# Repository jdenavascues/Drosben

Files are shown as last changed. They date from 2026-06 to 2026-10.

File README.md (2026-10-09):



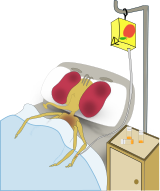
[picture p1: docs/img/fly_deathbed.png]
deathbed


# Drosben: a method for scaling up lifespan analysis of _Drosophila_

_Drosophila melanogaster_ is a powerful model organism to study ageing, or any other processes where lifespan is a useful life history trait, because the fly lends itself to large demographic studies to measure survival time and mortality rates. However, performing these experiments is time-consuming, as they require many manual passages of fly vials to keep them on fresh food and record events. 

We have developed a toolkit that allows transferring flies from 12 tubes into fresh ones ('flipping') simultaneosly, which we have named _Drosben_ (a portmanteau of _Drosophila_ and _trosben_, Welsh for sommersault). Drosben comprises both hardware (which can be made cheaply with 3D printing and minimal DIY modifications) and software (a simple python module with notebooks for usage). One speeds the manual labour, and the other one speeds the data recording -- producing a quick preliminary analysis and a spreadsheet ready to be analysed in a more targeted way in R with the package `survival`.

---

For more details, please refer to our paper describing the Drosben system together with a few new observations using this approach:

Terrence M. Trinca, Pau Berenguer-Molins, Cristina Fernández-García, Joaquín de Navascués.

Drosben, an affordable system for scalable survival analysis in _Drosophila_.

bioRxiv 2026.07.02.736118; doi: [https://doi.org/10.64898/2026.07.02.736118](https://www.biorxiv.org/content/10.64898/2026.07.02.736118)

---

# Overview

The Drosben system comprises:

- **3D-printed hardware** that has to be printed and assembled (glueing and some cutting).
- **Software** that has to be installed manually and used in three steps:

- _'Colour calibration'_ to validate a set of 3 marker pens for automatic recognition (done only once or if a new pen set needs to be tested);
- _'Experiment initialization'_ to record experimental design details and produce experiment-specific data recording sheets (done once per experiment);
- _'Data compilation/analysis'_ to capture the data from scanned datasheets (done once at the end of an experiment, but can also be done along the way to monitor progress).

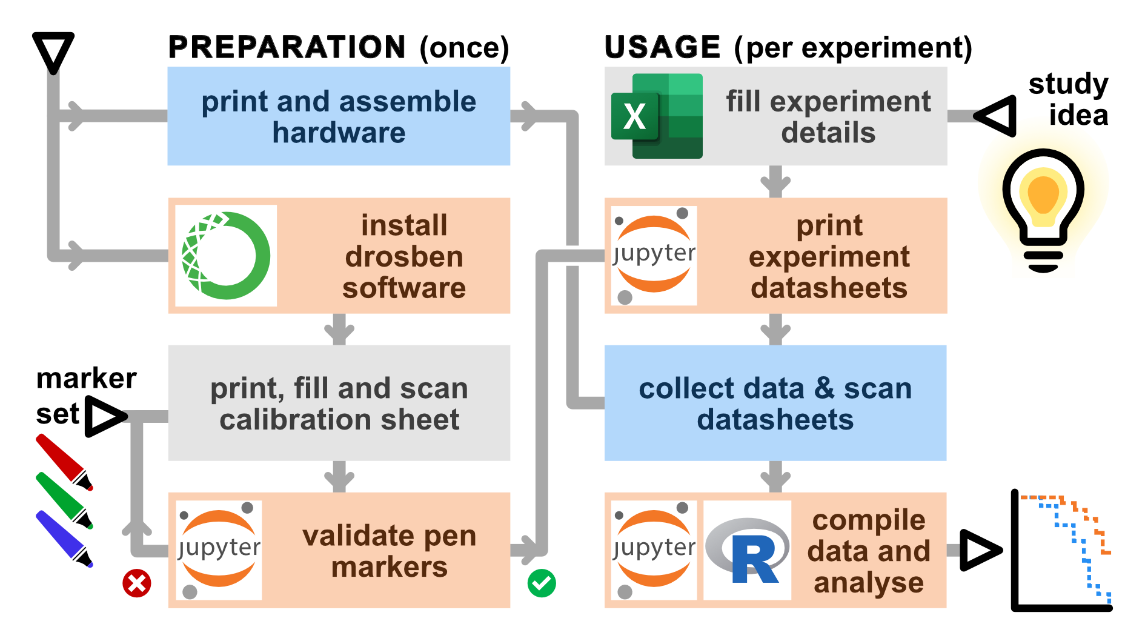
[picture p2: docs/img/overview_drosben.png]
Overview of the Drosben system: preparation and usage


---

# 1. The Drosben hardware

The hardware components are designed to improve handling speed of vials during fly transfer to fresh food.

## 1.A. Components

The Drosben hardware components are:
- The rack and lid that houses 12 _Drosophila_ vials,
- The depositor for distributing the flies initially into the vials,
- The multiflipper and its slider, for transferring the flies from a rack into another one with fresh vials.

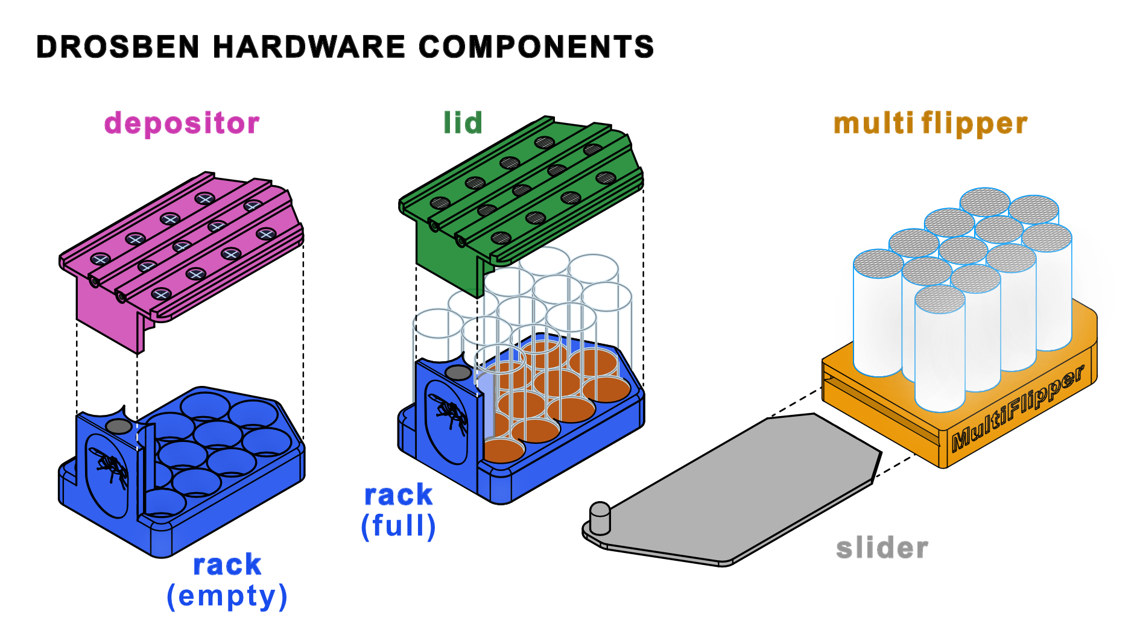
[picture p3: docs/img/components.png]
components of Drosben hardware


## 1.B. Required equipment and materials  

See the [hardware README](hardware/README.md) for the model files for 3D printing and some details on their assembly/preparation for usage.

+ **A 3D printer** capable of printing 1.75 mm PLA or ABS filament. We have printed the necessary parts successfully in a [Prusa i3 MK3S+](https://www.prusa3d.com/product/original-prusa-i3-mk3s-10th-anniversary-edition-3d-printer/) and a [Bambulab A1 mini](https://bambulab.com/en/a1-mini). Alternatively, you can send the files to a printer shop.

+ **Slicing software** for your 3D printer. We have used Cura Ultimaker and Bambulab Studio.

+ **Clear acrylic tube** with 25 mm outer diameter and 2 mm thickness (23 mm ID). These can be bought cut to measure from local or online retailers, or bought by the metre and take to a workshop for cutting. A cheaper alternative is to buy a long piece and cut it down yourself (see the [hardware README](hardware/README.md)).

+ **Stainless steel or plastic thin mesh**; those described for insect netting would work and are relatively cheap. A piece of ~15 x 20 cm will be enough for a single Multiflipper.

+ **Cyanoacrylate-based universal glue** such as those manufactured by Gorilla, Everbuild or Superglue. There is no need to use a special manufacturer but we prefer the gel presentation (as opposed to 'thin', 'extra thin' or 'highly penetrant') as these will run everywhere and can create frosting in the acrylic tubes.

+ **Silicon rubber sheet** of 1mm thickness, cut from a piece of approximately 30 x 20 cm (half to make a single Depositor, the other half to protect the Slider while gluing the Multiflipper).

+ **N45 Neodymium magnets** (3mm thick, of diameters 12mm and 6mm). Four will be needed for one Multiflipper (6mm &#x2300;), two for one Rack and Lid, and one for a Depositor (12mm &#x2300;).

> [!TIP]
> The fumes from the cyanoacrylate may leave a frost mark on the acrylic tubes; to prevent this, one may use use instead acrylic-specific glue to bind the tube segments to each other.

> [!CAUTION]
> **[1]** 3D printers release plastic microparticles and therefore pose a chemical hazard: make sure you follow local health and safety rules (and common sense) if you print yourself. **[2]** Cutting acrylic tubing yourself poses safety hazards (cuts and grazes): make sure you follow local health and safety rules (and common sense) if doing so. This also applies (somewhat less so, but to some extent) to rubber sheet. **[3]** Both cyanoacrylate and acrylic glues pose chemical hazards: make sure you follow local health and safety rules (and common sense) when using them.

## 1.C. Hardware usage

The Drosben hardware is used in three steps.

First, print and cut the rack labels for your experiment and place each in the slot of a rack, so you can see experimental conditions. Place the corresponding flies in each of the tubes using a pooter, with the distributor covering the tubes. The rubber valves of the distributor (see the [hardware README](hardware/README.md)) prevent flies from escaping. Quickly swap the distributor by a lid, where instead of valves, slits allow breathing. Both snap in place thanks to the rare-earth magnets and two rigid push-click spots. This starts the experiment. If you want to record the data blind to the experimental conditions, flip now each rack label so it is the QR side that shows.

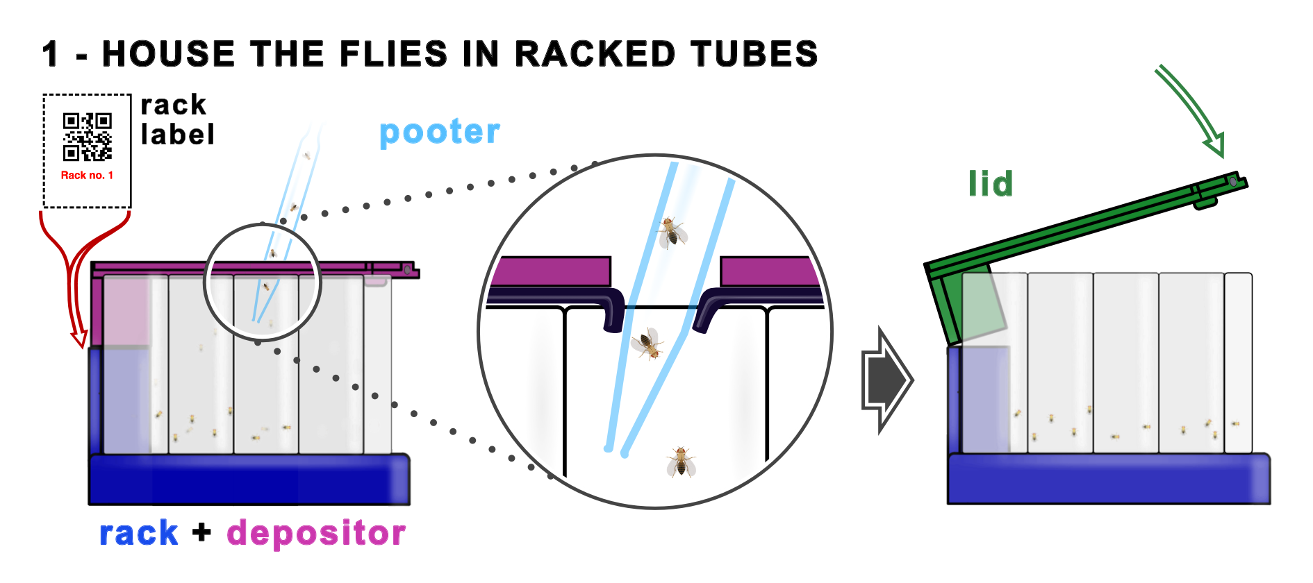
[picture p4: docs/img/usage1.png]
step1


Next, and every time flies need passaging into vials with fresh food, swap the lid by the multiflipper, flip the assemble and gently tap the flies into the multiflipper chambres; cover them with the slider, which will be held in place by magnets (see the [hardware README](hardware/README.md)). Set the rack with old tubes aside for recording deaths and place a new one on top of the multiflipper. Remove the slider, flipe the assemble and tap the flies into the new tubes. Swap the multiflipper and the lid and place the tubes in the incubator.

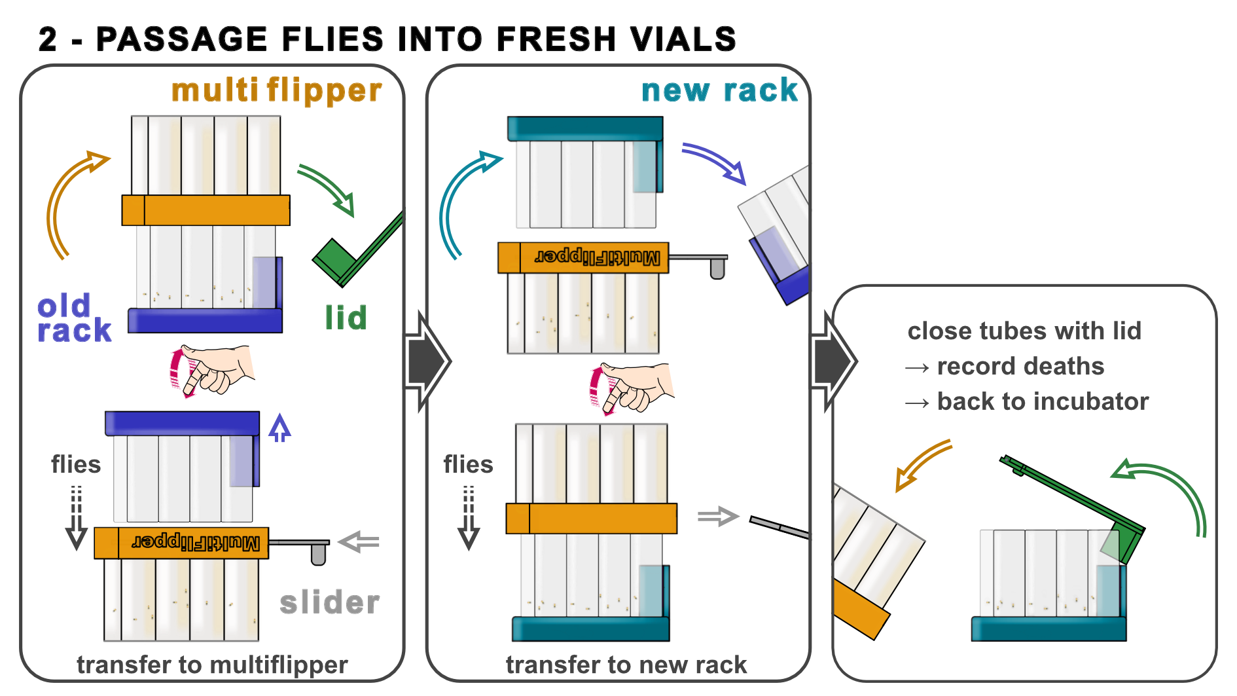
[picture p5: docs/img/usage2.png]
step2


Finally, every time you passage the flies, identify the datasheet corresponding to the rack you are passaging. Explicit datasheets will have the rack no. and the experiment 'name' and conditions in the header. For blind recording, read the QR code with the phone and match the reading with the last 5 characters of the experiment ID. Then, on the next available grid on the datasheet, record:
- days since last flip,
- deaths (matching the dead flies stuck to the bottom of the tubes),
- censorings (escaped flies or flies stuck alive to the bottom of the tubes), and
- carried-overs (dead flies that fall into the fresh vials).
When the experiment is finished (or you want to inspect the data), scan the datasheets and use the software.

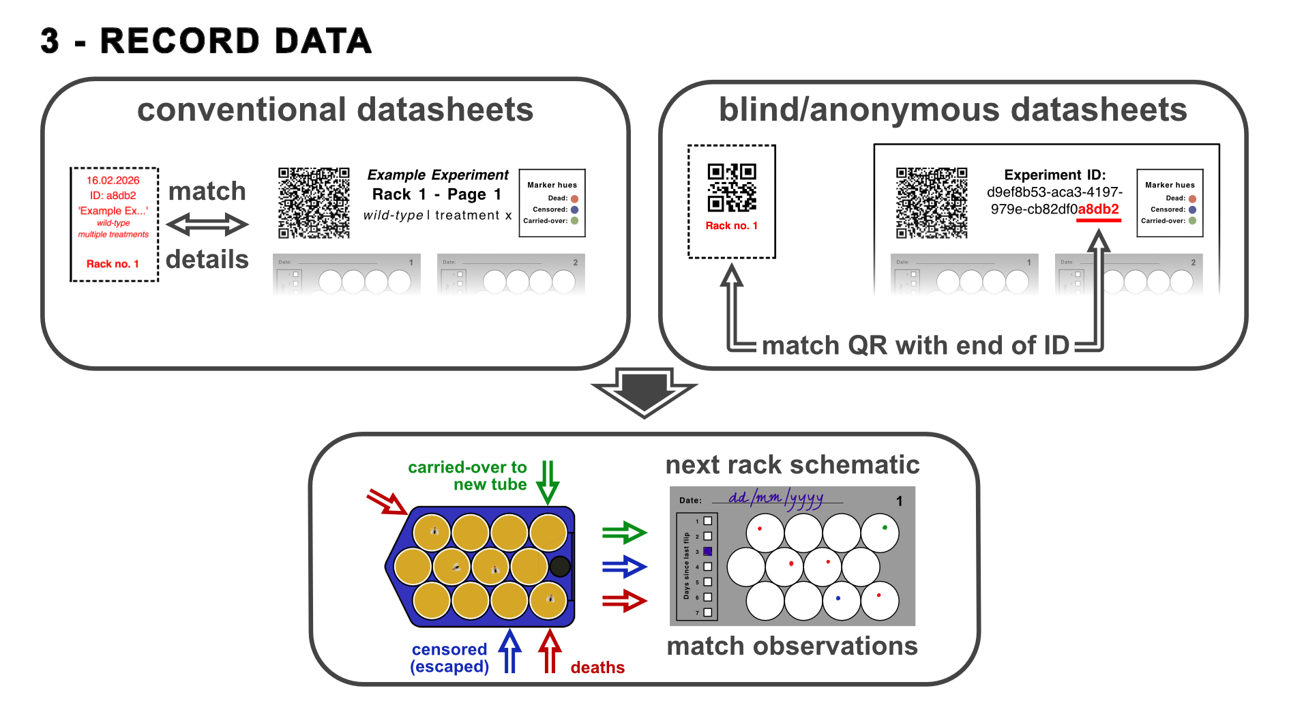
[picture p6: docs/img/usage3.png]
step3


---

# 2. The Drosben software

We wrote a python package to speed up the data collection, both when recording fly deaths and when compiling the observations in electronic form. It takes advantage of the shape of the tubes as held in the rack, so the user at the bench can quickly record deaths as pen marks on a printed template; then these can easily be scanned, automatically detected with computer vision, and compiled into a spreadsheet for analysis. So, while the hardware can be used without the software, this is not the case the other way around; however, the drosben system is more effective when both hardware and software are used together.

Apart from the hardware components, you will also need:

+ A colour printer
+ A device to scan A4 documents (ideally, a flatbed scanner, but a phone can work too)
+ 3 colour markers. We normally use Sharpie fine point markers in red, green and blue. More colourblind-friendly combinations could be obtained using yellow, orange, blueish red, purple light and blue.

> [!IMPORTANT]
> **Why using 3 colours?** Most of the data is collected with one colour (dead flies). However, sometimes flies can escape; while they can be ignored, the best practice is to record these as censored events -- hence the second colour. The third colour comes from the fact that, occasionally, a dead fly does not get stuck to the food; it dries too quickly and is carried over the new tube with the alive flies. These 'events' can be detected easily because the 'carried-over' corpses fall to the bottom of the tubes and remain immobile in unnatural positions. Recording this as a normal death can lead to counting the same dead fly as many times as it is carried over until it gets stuck to the food. So, every carried-over event has its own colour, and by recording them every flip they are detected, the software back-tracks the time of observed death to the first carried-over event.

## 2.A. Installation and start

### Installation with _no previous experience_ in programming

If you have _any_ experience programming in Python, you probably can jump to the [next section](#installation-with-any-programming-experience). If you do not have Python or '(ana)conda' installed in your system (or do not know if you do), this section is meant for you.

We are not experienced programmers, so neither our software nor its installer have polished user interfaces. However, they are simple enough and the steps are very constrained. Just bear in mind that instead of clicking and dragging-and-dropping, you will have to type in some simple commands, which we have tried to minimise and explain step by step.

We have written the drosben software in the Python language, using a few specific Python libraries (specialised extensions of the language). For our software to work, specific versions of both Python and the libraries need to be installed together; this is called an 'environment' (for some beginner explanations, see [here](https://realpython.com/python-virtual-environments-a-primer/), [here](https://www.w3schools.com/python/python_virtualenv.asp) or [here](https://www.anaconda.com/blog/anaconda-python-complete-beginners-guide).

Once you have the environment set up, you can open in it a 'working environment', JupyterLab, from where to open and run the so-called 'ipython notebooks' - a sort of live documents where you can mix formatted text (which we use to give you instructions) and snippets of code (which will work as the buttons and check boxes of a polished user interface). You can find basic explanations of what Jupyter Notebooks are and what they look like [here](https://www.datatoinsight.org/jupyter-notebooks) and [here](https://www.datatoinsight.org/jupyter-notebooks); for a bit more information look [here](https://www.datatoinsight.org/jupyter-notebooks) (shortcuts and hotkeys) or [here](https://www.dataquest.io/blog/jupyter-notebook-tutorial/) (with basic exercises); for a video tutorial, I suggest you look [here](https://www.youtube.com/watch?v=Ou-7G9VQugg). All these will give you more than you need, as we will only ask you to:
- open a notebook within JupyterLab
- 'run cells' (Shift-Enter)
- type in some cells the paths to the scans where you collected the data, guided by the instructions.

All this may sound like a lot, but it will be taken cared of by the 'environment manager' [Anaconda](https://www.anaconda.com/). Anaconda has paid options, but to run drosben, a free licence works perfectly; you just need to register.

#### Installing Anaconda

You first need to decide [which Anaconda version you want](https://www.anaconda.com/docs/getting-started/anaconda/install). Anaconda has two interfaces: a graphical one (the 'Anaconda-Navigator') and a command-line. The full version of Anaconda includes the Navigator and takes a minimum of 5Gb of hard disk space. If this is a concern to you, you can instead install Miniconda, which by default only has the command-line interface (CLI). Linux and MacOS systems have built-in 'command-line terminal' apps from where to use the CLI. Windows systems typically do not, but both Anaconda and Miniconda for Windows come with their own terminal apps: "Anaconda Prompt" (just to operate anaconda) and "Anaconda PowerShell Prompt" (more general-purpose). Alternatively, you can install a separate program to run command-line terminals. [MobaXterm](https://mobaxterm.mobatek.net/) is a general-purpose terminal utility and its free home licence is enough for running drosben. 

So, to install Anaconda, visit their [download page](https://www.anaconda.com/download), choose the system (Win/Mac/Linux) and version ('Ana'/'Mini') and run the installer. All of this is done clicking - no command line needed.

#### Copying the drosben source code

At the top of this GitHub page, click on the $${\color{#3E7E40}{\textsf{<> Code &#x2304;}}}$$ button and select 'Download ZIP'. Unzip the contents and move the folder to where you want it to be.

#### Creating the drosben environment

**With Anaconda-Navigator:** Open the Navigator and follow the instructions from the Anaconda tutorial to [import an environment](https://www.anaconda.com/docs/tools/anaconda-navigator/tutorials/manage-environments#importing-an-environment) using a local `.yml` file. The local file for you is `environment.yml`, directly in the `drosben/` folder you just unzipped.

**With command-line:** Open a terminal in your system.
- Linux: press the Super key and type 'terminal'.
- MacOS: navigate to Applications > Utilities > Terminal
- Windows: press the Windows key, type 'Anaconda Prompt' or your utility of choice
Once in the terminal, just run in your terminal (copy-paste-&#x21B5;):
```{bash}
# navigate to where the drosben repository is
cd ~/where/you/have/drosben # substitute this path for the one in your system
# create the environment (drosbenV - name determined by environment.yml)
conda env create -f environment.yml
# activate it
conda activate drosbenV
# install the drosben package as local source
# (this is installed in the drosbenV environment)
pip install drosben
# ONLY if you installed miniconda, JupyterLab needs to be installed separately:
# (this is installed in the drosbenV environment)
conda install -c conda-forge jupyterlab -y
```
Simple!

---

### Installation _with_ any programming experience

If you have any programming experience with python, you can probably jump over this paragraph. If you have programming experience but not with python: for the software to work reproducibly, we need an environment with a specific version of python (3.11) and the libraries used (some in specific versions, too). The environment manager Anaconda does this and installs JupyterLab (an IDE to run the code through computing notebooks).

- [Install Anaconda](https://www.anaconda.com/download) in whichever version you prefer, if you need to.
- Open a shell terminal and run:
```bash
# clone the repository and go to its top directory
cd ~/where/you/want/the/repo
git clone https://github.com/jdenavascues-trincatalyst/drosben.git
cd drosben
# create the environment
conda env create -f environment.yml
# activate it
conda activate drosbenV
# install the drosben package as local source
pip install drosben # note ~/.../drosben is the working directory
# if using miniconda, add JupyterLab
conda install -c conda-forge jupyterlab -y
```

---

### Running the program once installed

JupyterLab will run the notebooks from where you can use the drosben software. To start JupyterLab:

**With Anaconda-Navigator:** Launch the Navigator, go to the Home tab, and find the drop-down menu that selects the environment. It is at the top and will probably read "_All applications_ on _base (root)_". Change _base (root)_ for _drosbenV_, and click on the JupyterLab launch icon.

**With command-line:** In a shell terminal, run:
```bash
conda activate drosbenV
cd ~/.../drosben # so jupyterlab starts there and notebooks are easy to find
jupyter lab
```

Once JupyterLab is active, navigate interactively to the `drosben/notebooks/` directory and open the Notebook you need. The first time, do it in their numerical order. Any alternative IDE that can run the notebooks should work, too.

---

## 2.B. Usage and data analysis

The easiest way to use the software is to run the Jupyter notebooks in order:
- [Colour test template](src/drosben/resources/colour_cal_printout.pdf): Print, fill and scan this template start Notebook #01 (see notebook for detailed instructions).
- [Notebook #01](/notebooks/01_First_Use_Colour_Calibration.ipynb): Validate the pen markers to ensure the three colours will be discriminated without human supervision. This needs be done only once, unless you change the colours.
- [Excel template](src/drosben/resources/experiment_template.xlsx): Before you start an experiment, fill in the experimental details in an Excel template file.
- [Notebook #02](/notebooks/02_Perform_Experiment.ipynb): Read the experiment metadata from the Excel template and generate
    - experiment-specific data recording sheets. These can be anonymous for blind data collection, if desired, and
    - Labels for each of the racks used for the experiment racks (both anonymous or identified).
    - This only needs be run once per experiment.
- [Notebook #03](/notebooks/03_Read_DataSheets.ipynb): Compile the observations recorded in scanned datasheets and run an automated preliminary analysis of the data. This can be done all at once at the end of the experiment or incrementally, in multiple rounds along the way.
- Then move to an R environment (e.g. RStudio) for [Notebook #04](/notebooks/04_Analyse_Data.Rmd)

Recommendations for scanning datasheets and colour calibration sheets:
- Scan the papers at ≥150 dpi
- Save in TIFF/JPEG/PNG/PDF format
- You can use a phone or a flatbed scanner (but see below)
- For datasheets in particular:
    + They require minimal skew (which can be corrected up to a few degrees) or perspetive distorsion (which is not corrected by drosben and needs to be adjusted beforehand).
    + QR corner MUST be visible.

### Further analysis in R

The output of the python notebooks will be a spreadsheet (XLSX/CSV) that can be analysed in python, but is best analysed using the `survival` package in R. The libraries for survival analysis in python are simply not as well developed as in R. To use R, the easiest way is:

- Download the R installer for your system from [CRAN](https://cran.r-project.org/) and follow its instructions for installation.
- Download the RStudio Desktop installer from [posit](https://posit.co/download/rstudio-desktop/) and follow its instructions for installation.
- A nice introduction from absolute zero to R and RStudio is provided by [the Sydney R-Ladies](https://rladiessydney.org/).
- You will need to install the packages [`survival`](https://cran.r-project.org/web/packages/survival/) by Terry Therneau and [`survminer`](https://cran.r-project.org/web/packages/survminer/index.html).
- We do not cover the use of these here at this point. There are multiple tutorials that show how to use these libraries:
    - [Tutorial by Emily Zabor with some basic theory](https://www.emilyzabor.com/survival-analysis-in-r.html)
    - [Tutorial by Shariq Mohammed](https://shariq-mohammed.github.io/files/cbsa2019/1-intro-to-survival.html)
    - [Tutorial at UCLA with some theory](https://stats.oarc.ucla.edu/wp-content/uploads/2025/02/survival_r_full.html)
    - [Tutorial at Datacamp](https://www.datacamp.com/tutorial/survival-analysis-R)
    - [Tutorial by Ho Thi Nhan](https://bookdown.org/nhanhocumc/biodata-r/survival.html)
    - [Tutorial by Aura Frizzati](https://rpubs.com/auraf285/SurvAnalysisR)
    - There's plenty more around...

## 2.C. Troubleshooting

(Under construction)

### Environment issues

If `conda env create -f environment.yml` fails to solve, try the more prescriptive installs (where the versions are more rigidly specified).

First using the pinned `.yml` file, where package versions are specified:
```bash
# with the repository top folder drosben/ as your working directory:
conda env create -f environment_pinned.yml
# follow up with environment activation, etc
```

If that fails, try cloning a locked environment that we used successfully:
```bash
# with the repository top folder drosben/ as your working directory:
conda-lock install -n drosbenV -f conda-lock.yml
# follow up with environment activation, etc
```

### Test the installation

- To run tests:
```bash
pytest -q
```
If this runs without errors, you should be ready to go.

### Jupyter does not seem to have the right libraries

JupyterLab and the Jupyter notebooks will only be 'aware' of drosben if they were initialised within the `drosbenV` environment. If you try to run the notebooks code cells and you get error messages along the lines of `` maybe you have not started from this environment. Create a new cell in the notebook and run:
```python
import os
print(os.environ['CONDA_DEFAULT_ENV'])
del os
```
This code block should print `drosbenV`. If it doesn't, exit JupyterLab with File > Log Out, go back to Anaconda-Navigator or your Terminal and try again the [instructions above](#running-the-program-once-installed).

---

# 3. Contact

- [**Terrence M Trinca**](https://www.bristol.ac.uk/people/person/Terrence-Trinca-4379516b-71e2-40a1-9e22-a4a3fb2bdda9/)
- [**Joaquín de Navascués**](https://www.essex.ac.uk/people/DENAV35604/Joaquin-De%20Navascues)

---

# 4. Acknowledgments

* Hat tip to all the programmers from whom we took tips and tricks found in StackOverflow and GitHub. Their contributions are linked in comments in the code.
* The sickly fly was drawn by [Cristina Fernández García](https://es.linkedin.com/in/fernandezgarciacristina).
* [Flying fly silhouette in one of the figures](https://www.vexels.com/vectors/preview/170043/fly-insect-silhouettes")

---

# 5. License

The contents of this repository are shared through the MIT licence. 

---

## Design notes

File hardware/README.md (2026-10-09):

# Instructions to assemble the Drosben components

> [!CAUTION]
> 
> Assembling the hardware brings chemical and mechanical hazards.
> We give recommendations but you follow them **at your own risk**.
> 
> **THIS IS NOT A RISK ASSESSMENT**. Some precautions are mentioned, but you **must** do your own risk assessment.

You will need:

## Component costs[^*]

| Component | Quantity | Required[^a] | Cost per usage unit |
| :--- | ---: | :--- | ---: |
| (initial materials) | 1 | Per lab | £71.00 |
| Depositor stencil | 1 | Per lab | £0.14 |
| Multiflipper | 1 | Per user | £38.91 |
| Slider | 1 | Per user | £0.50 |
| Depositor | 1 | Per user | £3.49 |
| Rack | 2 | Per cohort | £2.28 |
| Lid | 1 | Per cohort | £0.90 |

## Materials costs

| Material | Quantity (per pack) | Unit | Price[^b] |
| :--- | ---: | :--- | ---: |
| PLA filament | 1000 | g | £18.00 |
| Acrylic tube | 1 | count | £3.00 |
| Nail shaft | 200 | count | £3.50 |
| N52 magnet 12 x 3 mm | 50 | count | £12.00 |
| N52 magnet 10 x 3 mm | 50 | count | £12.00 |
| Woven wire mesh | 3600 | cm² | £20.00 |
| Super glue gel | 30 | g | £4.00 |
| Acrylic cement | 50 | ml | £9.00 |
| Rubber sheet | 100 | cm² | £3.00 |

## Recipes

| Component | Material | Quantity | Unit | Cost per component |
| :--- | :--- | ---: | :--- | ---: |
| Multiflipper | PLA filament | 40 | g | £0.72 |
|  | Acrylic tube | 12 | count | £36.00 |
|  | N52 magnet 10 x 3 mm | 4 | count | £0.96 |
|  | Woven wire mesh | 120 | cm² | £0.67 |
|  | Super glue gel | 0.2 | g | £0.03 |
|  | Acrylic cement | 3 | ml | £0.54 |
| Depositor | PLA filament | 21 | g | £0.38 |
|  | Rubber sheet | 100 | cm² | £3.00 |
|  | Nail shaft | 4 | count | £0.07 |
|  | Super glue gel | 0.3 | g | £0.04 |
| Lid | PLA filament | 32 | g | £0.58 |
|  | N52 magnet 12 x 3 mm | 1 | count | £0.24 |
|  | Nail shaft | 4 | count | £0.07 |
|  | Super glue gel | 0.1 | g | £0.01 |
| Rack | PLA filament | 50 | g | £0.90 |
|  | N52 magnet 12 x 3 mm | 1 | count | £0.24 |
| Slider | PLA filament | 26 | g | £0.47 |
|  | Nail shaft | 1 | count | £0.02 |
|  | Super glue gel | 0.1 | g | £0.01 |
| Depositor stencil | PLA filament | 8 | g | £0.14 |

## Tools

| Tool | Assumed available | Cost | Optional[^c] |
| :--- | :---: | ---: | :---: |
| Pliers (to clip nail heads) | yes | £10.00 | no |
| Cutter (to cut mesh and rubber sheet) | yes | £10.00 | no |
| 3D printer | yes | £140.00 | no |
| Silicon sheet, 0.5 mm thick (to glue the multiflipper) | no | £4.50 | no |
| Arc saw | yes | £10.00 | yes |
| 25 mm pipe cutter | yes | £50.00 | yes |
| 3D-printed tube cutter reference tool[^d] | yes | £1.50 | yes |

[^*]: Prices were estimated in July 2026.
[^a]: The Depositor and Multiflipper could be shared between users, but for real scalability, it is better to assume they will not be. A rack can house cohorts of up to 180 flies (15 per tube).
[^b]: Prices have been ceiled to the nearest £1. These are realistic indicative prices, but the exact cost of the initial investment and component may change depending on the specific retailer and the configuration of the pack. Most components have been obtained from non-specialist online retailers, except the acrylic tubing and the woven wire mesh, which are respectively from Simple Plastics and The Mesh Company (both UK companies).
[^c]: Optional tools allow the user to buy 25 mm acrylic tubing in 1 m lengths and cut out their own segments for the multiflipper chambers. This makes the tubes, which are one of the most expensive parts, a bit cheaper (as each cut needs to be paid for separately).
[^d]: The model is within the 'Utilities' folder as 'tube_cutter_reference'.

> [!CAUTION]
> Most prints require the use of [supports for floating structures](https://store.anycubic.com/blogs/3d-printing-guides/3d-printing-supports). These need to be removed after printing using a flat screwdriver or a knife.
> Please use a cut resistant glove in the holding hand or a vise (but do not tighten it too much or you will crush the print).

> [!CAUTION]
> Acrylic cements (i.e. Tensol 12, Anglosol 12) are highly flammable and release toxic fumes.
> Cyanoacrlylate glue also releases toxic fumes and any splatter or running drop may glue your fingers together or to the parts.
> Do all the gluing in a well-ventilated space and wear gloves.

## Building the Racks

### Printing

Our latest prints were printed in a Bambulab A1 mini with plain PLA after slicing in BambuStudio with:

- the base of the Rack facing the printer's bed;
- preset configuration _0.08 mm High Quality_;
- support enabled (with support default settings).

The rack is the only model with <a href="https://github.com/jdenavascues/Drosben/blob/main/hardware/3D_models/Rack/Rack.stl" target="_blank">very thin areas</a>, where the tubes almost touch and in the sleeve to hold the label. We have not managed to print both faithfully - it seems to be either one or the other:

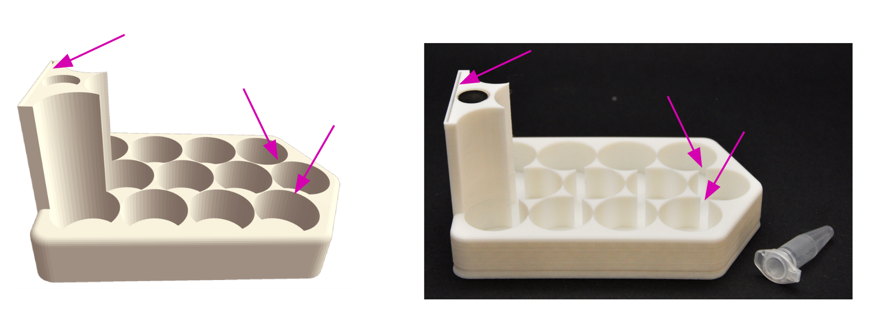
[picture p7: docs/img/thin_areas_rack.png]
thin_areas_rack


In our experience, hosting the tubes firmly does not need the full cylinder slot - the curved triangles are enough to keep the tubes secured. So we favour printing racks with functional sleeves, for which those settings work well.

### Post-printing modifications

## Building the Lids

### Printing

Our latest prints were printed in a Bambulab A1 mini with plain PLA after slicing in BambuStudio with:

- the top side of the Lid facing the printer's bed;
- preset configuration _0.12 mm High Quality_;
- support enabled (with support default settings).

### Post-printing modifications

Before gluing, check that the nails enter the opening of the rails with adequate tolerance. If they are too tight, get narrower nails or scrape the inner walls of the rails with a needle or a round coping saw blade. Once you are satisfied, cut off the heas of four nails, add a drop of glue to the tips and push them into the rail's cavities until the nails' ends are flush with the rail openings. Do not glue the magnets yet.

## Building the Multiflipper

### Printing

Our latest prints were printed in a Bambulab A1 mini with plain PLA after slicing in BambuStudio with:

- the top side of the multiflipper (the one that will host the chambers) facing the printer's bed;
- preset configuration _0.2 mm standard_;
- support enabled (with support default settings).

### Post-printing modifications

#### Obtaining the tubes for the chambers

The chambers are made from acrylic tube of 25 mm external diameter and 2 mm wall thickness, 70-100 mm long.

The easiest way to obtain these is purchasing long tube at a local workshop or online retailer and ask them to cut them down for you. They typically offer cutouts starting at 100 mm in length, with a fee per cut. This is convenient and gets you cuts of the best quality. However, there are advantages to cutting your own tubes: you can make tubes shorter (100 mm makes a bulky, heavy multiflipper), and it saves money in cuts and total tube length. The cuts will not be so clean, though.

You can cut your tubes with a mitre or table saw, but doing this safely and without notching the tubes requires more than basic DIY skill so we will not cover it here. If you think you can do it, you probably do not need our help.

To cut the tubes yourself safely and with reasonably good results, you can use our [_tube cutter with reference_ model](./3D_models/Utilities/tube_cutter_reference.stl) (printed  with _0.12 mm High Quality_ presets and support enabled). This tool was copied from a design by YouTube user M.S. Idris, who shows how to use it here:

cutting_tubes_yourself (http://www.youtube.com/watch?v=mZk1wDfr2mY "Good quality cuts of acrylic tubing with an arc saw")

We added minor modifications so the clamp works with rubber bands (faster than bolts) and it includes stainless steel sliding bars (15 cm rods, 3 mm diameter) with a stopper and a M4 bolt to fix the length for repeated cutting:

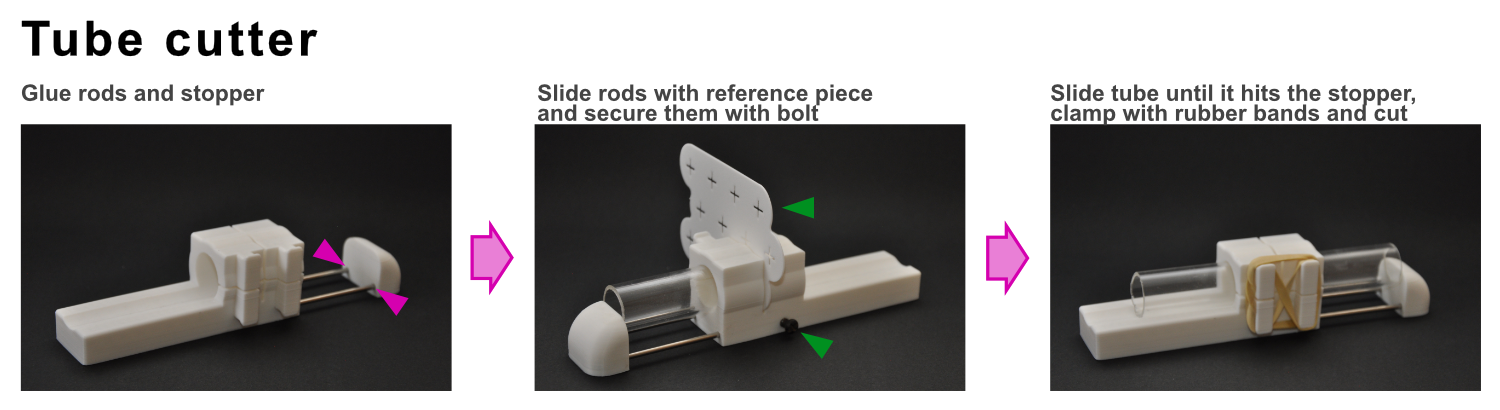
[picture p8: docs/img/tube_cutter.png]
tube_cutter_annotated


You will need a pipe cutter to score the tube, as shown in M.S. Idris' video. Cutting can be done with an arc saw, a tenon saw or a dozuki saw (Japanese woodworking pull saw).

#### Gluing multiflipper frame, chambers and mesh

Once you have 12 acrylic tubes, you have to glue them to each other, then glue the ensemble of tubes to the multiflipper 3d-printed frame, and then glue the mesh on top:

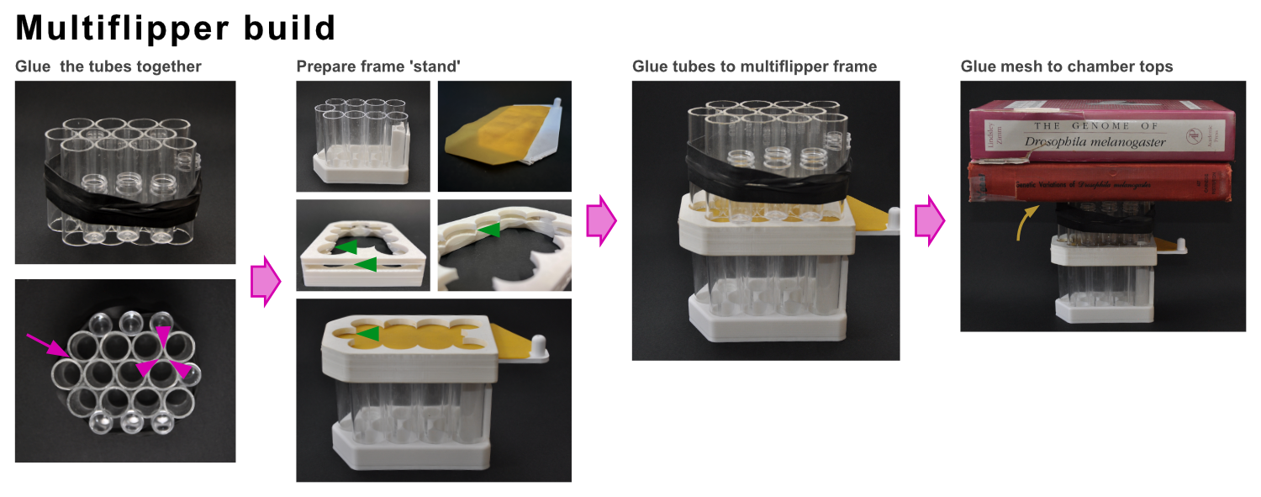
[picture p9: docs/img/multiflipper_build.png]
sequence


**To glue the chambers ensemble**, arrange the tubes in the same 4 x 3 honeycomb configuration as the rack and multiflipper, and hold them using rubber bands. Make sure they are **all flush with each other**. Using a Pasteur pipette, a metal rod or a syringe, run a generous drop of glue along both sides of the touching tangent of each tube pair (magenta arrows in the image above). Let them dry following manufacturer's instructions.

We have tried five different glues:

- Acrylic cement (Tensol 12, Bostik) gives excellent results. Tubes are essentially welded clean. However, it releases nasty volatiles, takes long to dry (24 hours) and once opened, the bottle often dries up before you can use all the cement.
- Cyanoacrylate (SuperGlue) is strong but releases volatiles that react with the surface of the acrylic plate and frost it, reducing visibility. Do not use.
- Plastic cement (Poly Cement, Humbrol) is designed for polystyrene and ABS. It cures fast (1 hour) but it is weak. Do not use.
- Super Plastic Glue (Bondtech) bonds in seconds to minutes, is strong and does not frost the surface of the acrylic tube. It also releases nasty volatiles, but it is a good option.
- UV Resin Glue (DecorRom) is odorless, and cures after exposure to UV light (included with the glue). It is strong and the cured seal is clear. One must be careful with the eyes, but it is a good option.

**To glue the chambers to the multiflipper frame**, it is essential that the base of the tubes is flush with the slot for the slider (green arrows in the image above). Therefore, a stand to hold the chambers at the right height is necessary. This is done resting the chambers on the slider, protected from the glue with a thin silicone rubber mat, cut out using the slider as a stencil. Insert the slider and the silicone cutout into the slot of the multiflipper frame, with the silicone mat towards the top of the base. Place the group on a rack with tubes, so the rubber can be pushed against the top (ceiling) of the multiflipper frame.

Then run the glue bottle nozzle along the internal edge of the top side of the multiflipper (where the tubes will be glued to) and place the tube array there, supported by the slider (which is covered by the silicone mat so it does not become glued.

Once the chambers are glued into a single solid, cut a rectangle of mesh that covers the tube array (with several mm of margin around) and flatten it as much as possible. Place it on top of the silicone rubber mat, on a strong horizontal surface. Run the glue bottle tip along all the rims of the acrylic tubes, without overflowing the rim, and place the mesh on top. Protect it with another piece of silicone rubber (yellow arrow in the image above), put some weight on it and let the glue cure. Once the glue has cured, use the cutter or a scalpel to cut the mesh along the outer edge of the tube array, to have it flush with the tubes.

Check that the tubes are flush with each other on the open side. If the are not, sand the excess until they are (mounting sandpaper on the slider), with care so the surface does not tilt.

## Lid and multiflipper: gluing the magnets

Glue two N52 disk magnets 10 x 3 mm to each round hole at the front of the multiflipper and the lids. Simply add a drop of cyanoacrylate glue gel to the slot for the magnet and place an N52 neodymium disk magnet (12 x 3 mm) there.

> [!TIP]
>
> **IMPORTANT:** You will want **all** your racks to have their magnets in the **same orientation**, so all your lids are compatible with any rack. But rare-earth magnets do not indicate their polarity. So, once you have glued the magnet to the first rack, use it as an indicator (once the glue has set!): let the next magnet you glue first attach to the glued magnet, add a drop of glue to the slot where it is going to go, and place it there in the required orientation as indicated in the schematic:
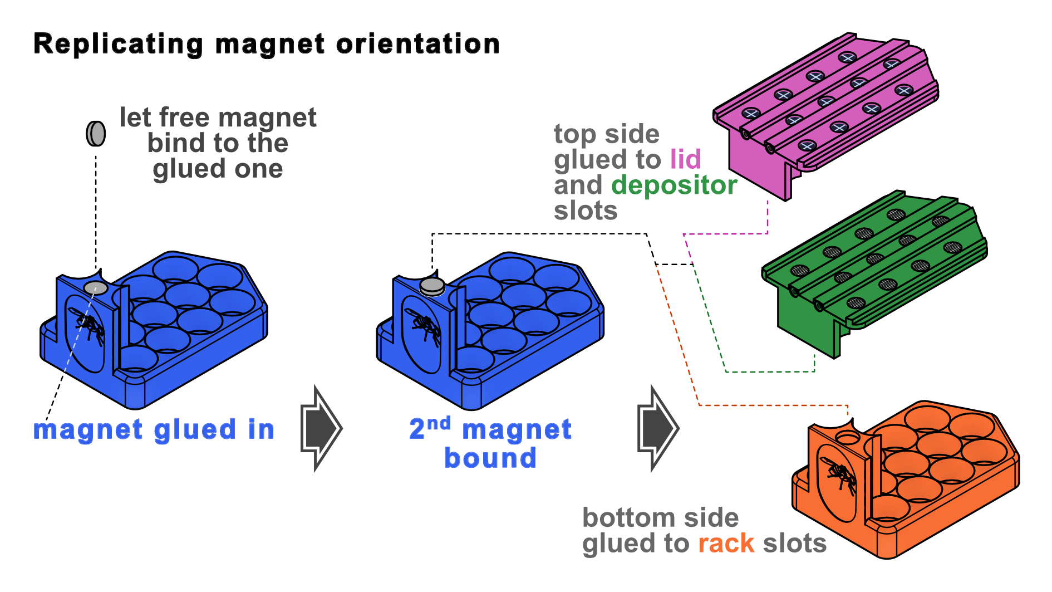
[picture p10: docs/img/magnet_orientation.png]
magnet_orientation
> 

## Slider

Print with the same settings as the multiflipper or the lid, with the top side on the printer's bed. No supports are needed.

Glue one nail into the hole at the tip, with the same precautions as in the rails of the lid and depositor (check tolerances first).

## Depositor

### Printing

Like the lid. Print as well a stencil, which can be a bit more relaxed (0.2 mm).

### Post-printing modifications

Using the <a href="https://github.com/jdenavascues/Drosben/blob/main/hardware/3D_models/Utilities/Depositor_stencil.stl" target="_blank">stencil</a> , use a cutter or a scalpel to cut a piece of neoprene rubber around it. Make sure the cross openings for cutting the cuspid valves have the wider side facing upwards. Press firmly against the rubber with the stencil and cut deeply and slowly - if you stretch the rubber while cutting, the final shape will not match well the outline carved in the depositor. Once the perimeter has been cut, without moving the stencil, make cross cuts in all the indicated places to align the cuspid valves with the holes in the depositor. Use a stack of old paper or soft wood as a base so you can cut through without damaging the working surface.

Run the cyanoacrylate glue gel bottle nozzle along the surface of the well for the rubber mat (bottom side, the opposite one to the rails), and press the rubber mat against it. Put some weight on it and leave to cure.

Add nails like to the lid.

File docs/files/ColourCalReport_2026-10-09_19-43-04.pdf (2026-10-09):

# Colour Calibration Results

## Calibration performed on 2026-10-09_19-43-04 Scan file: colour_configurations

## Potential problems with detection of dots

The resolution of this scan seems to be ~71dpi:
scan_RGB_Xerox.pdf
The recommended resolution is >150dpi. Drosben will interpolate to 150dpi.
The process will continue with the available data, but there may be problems after this point. Consider re-scanning the Colour Calibration Form.

## Potential problems with recognition of colour

## None

Hue

Saturation

## Marker hues

### Dead:

### Censored:

### Carried-over:

## Hue and Saturation windows to determine event colour

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

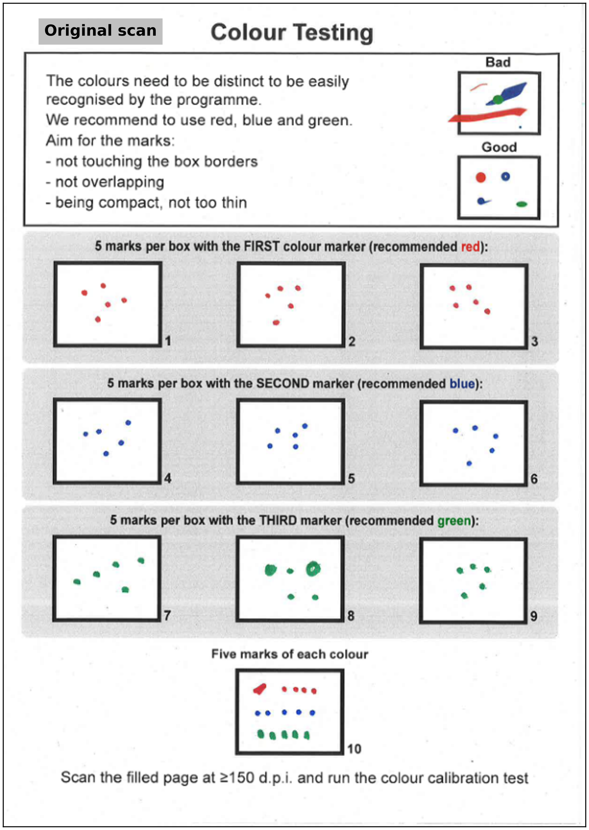
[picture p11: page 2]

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

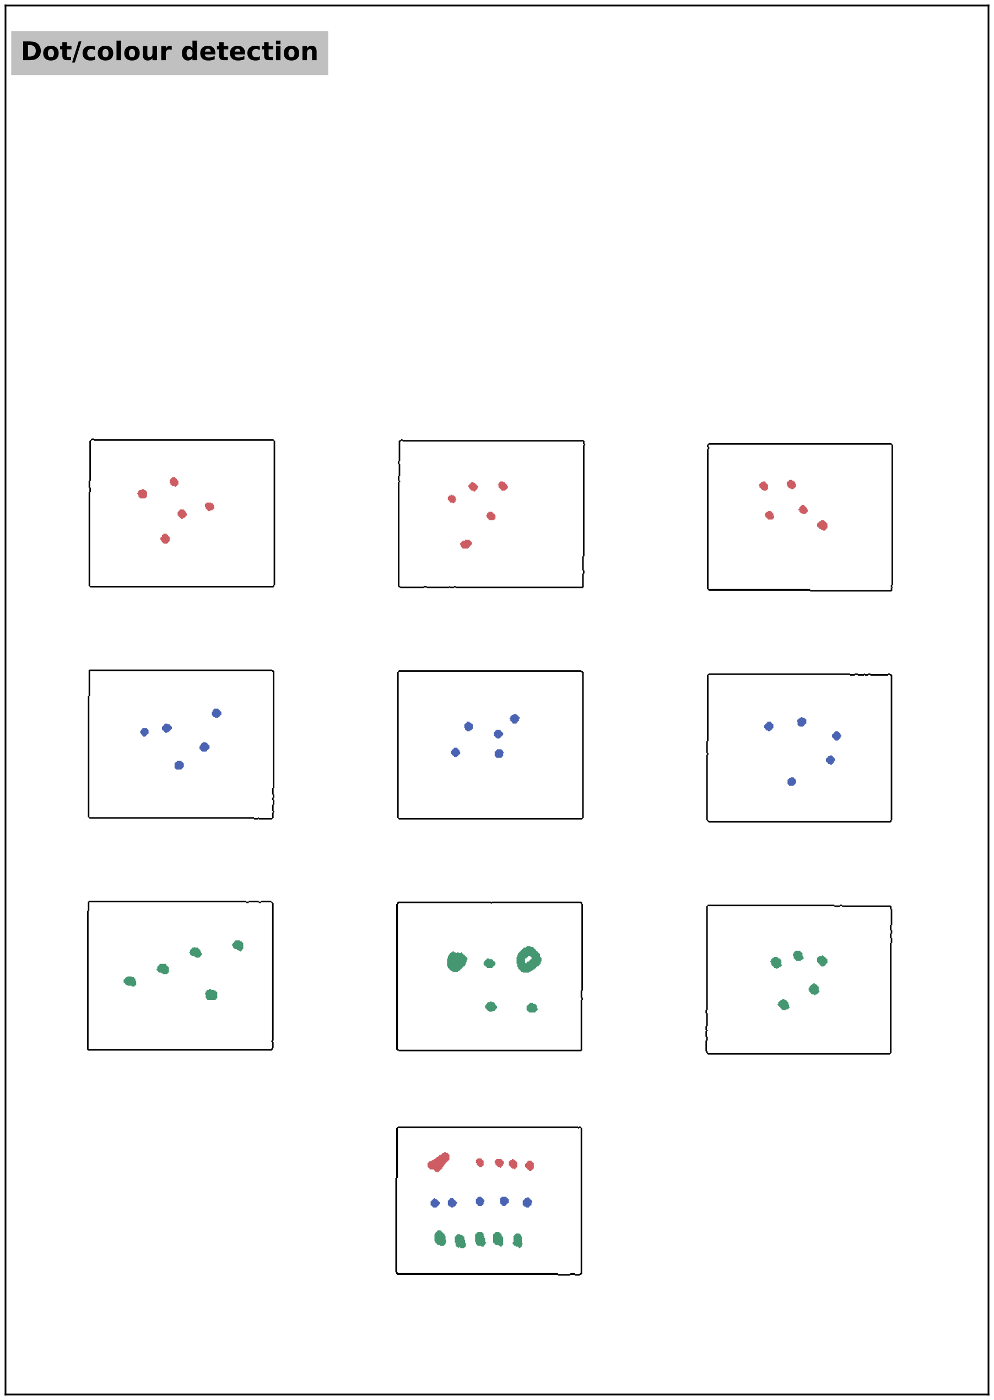
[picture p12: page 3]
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

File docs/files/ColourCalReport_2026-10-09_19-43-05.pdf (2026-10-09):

# Colour Calibration Results

## Calibration performed on 2026-10-09_19-43-05 Scan file: colour_configurations

## Potential problems with detection of dots

The resolution of this scan seems to be ~71dpi:
scan_YPlB_Xerox.pdf
The recommended resolution is >150dpi. Drosben will interpolate to 150dpi.
The process will continue with the available data, but there may be problems after this point. Consider re-scanning the Colour Calibration Form.

## Potential problems with recognition of colour

## None

Hue

Saturation

## Marker hues

### Dead:

### Censored:

### Carried-over:

## Hue and Saturation windows to determine event colour

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

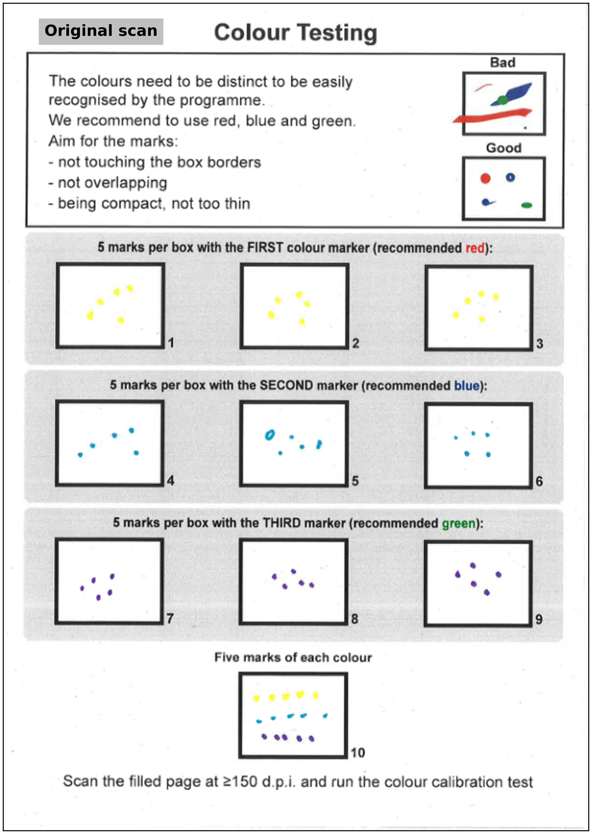
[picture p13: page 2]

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

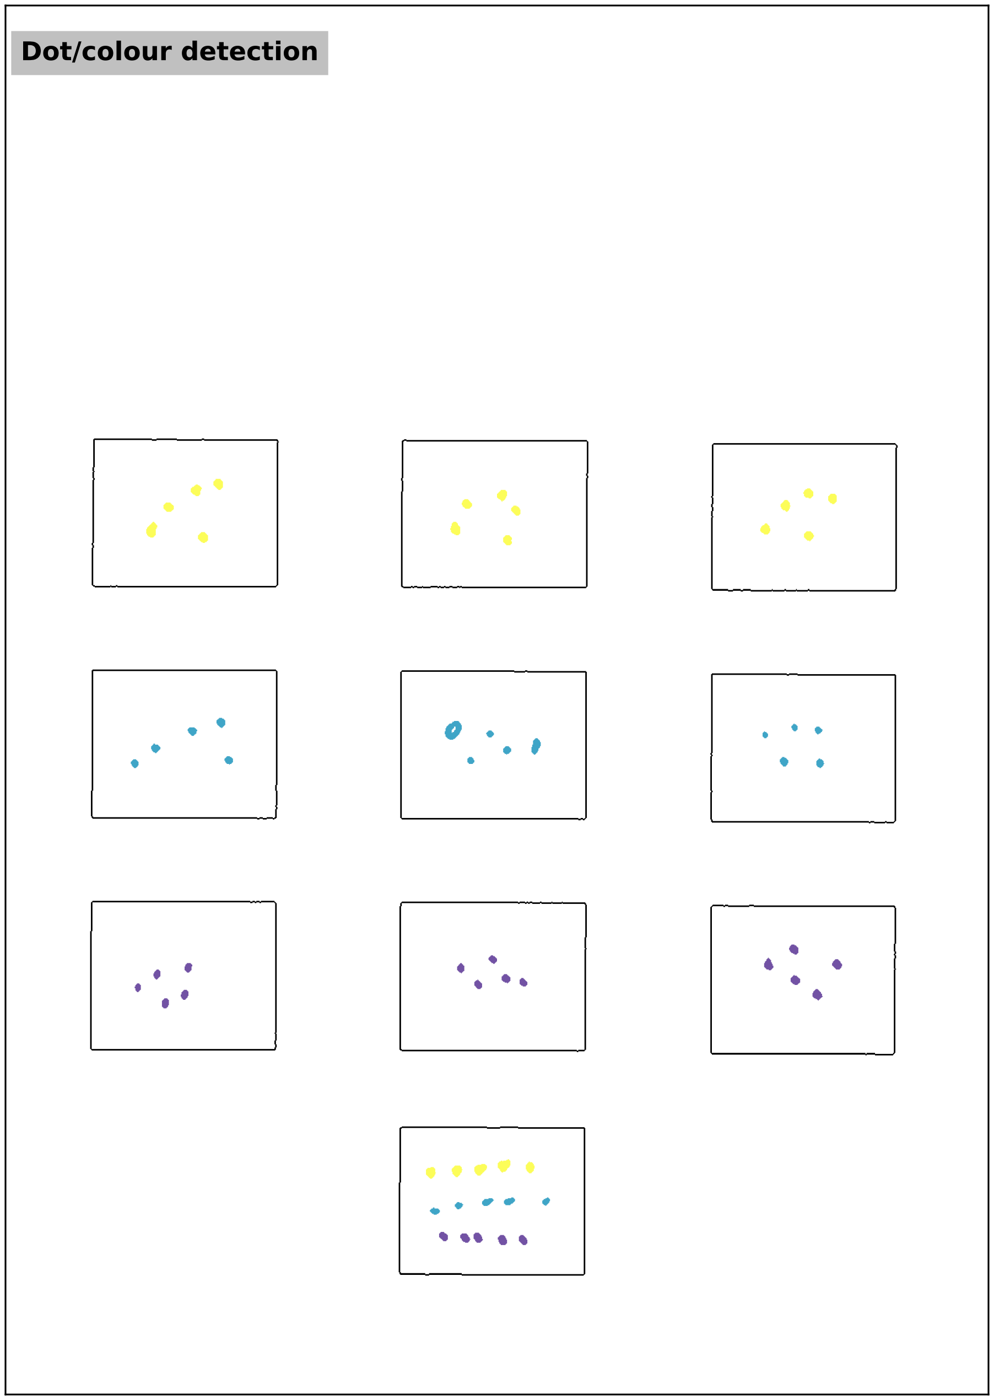
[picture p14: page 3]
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

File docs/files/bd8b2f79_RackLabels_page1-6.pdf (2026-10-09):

# Label printouts for Multiflipper racks

## For experiment:

Cut along the dashed line and place in the rack pocket. Each label can be mapped to a DataSheet form by either reading the QR code with the phone (anonymised) or with the experiment data and rack number (non-anonymised).

Effect of myfavouritegene on lifespan

Rack no. 1

Rack no. 1

02.02.2022
ID: bd8b2
'Effect of ...'
wild-type
mock

Rack no. 2

Rack no. 2

02.02.2022
ID = bd8b2
'Effect of ...'
mfg[1]
mock

Rack no. 3

Rack no. 3

02.02.2022
ID = bd8b2
'Effect of ...'
wild-type
treated

Rack no. 4

Rack no. 4

02.02.2022
ID = bd8b2
'Effect of ...'
mfg[1]
treated

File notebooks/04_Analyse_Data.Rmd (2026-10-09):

---
title: "4. Analyse Drosben survival data "
author: "Terrence M. Trinca and Joaquín de Navascués"
output:
  html_document:
    code_folding: hide
    theme: united
    toc: yes
    toc_float: yes
    toc_depth: 3
    highlight: haddock
---

## 4A. Setting up

### Computing tools

If you have not used R before, you are probably reading this in its HTML version
and you do not know how to run an R markdown notebook. If this is the case, our
recommendation is that you first install R and RStudio from [the Comprehensive R
Archive Network, CRAN](https://cran.r-project.org/) and the [Posit Software,
PBC](https://posit.co/download/rstudio-desktop) download sites, respectively,
and follow their instructions. It just takes a couple of minutes. If you feel a
bit lost, the R-ladies' Sydney chapter has a nice ['basic-basic' tutorial to
using RStudio](https://rladiessydney.org/courses/01-basicbasics-0).

Once you have done this, you can just double-click on the 'Rmd' version of this
notebook to run it as you ran the Jupyter notebooks.

All the analysis examples here are just using the work of (mostly)
Dr Terry M Therneau
([Survival package](https://cran.r-project.org/web/packages/survival/))
and (again, mostly) Alboukadel Kassambara
([Survminer package](https://cran.r-project.org/web/packages/survminer/))

```{r setup, cache = FALSE,  message = FALSE, warning = FALSE}
require(librarian)
librarian::shelf(
  tidyverse, readxl,
  survival, survminer, glue,
  gtsummary, kableExtra,
  ggthemes, ggtext, ggnewscale, RColorBrewer,
  grid, gridExtra, # TMT
  knitr,
  rstudioapi, # TMT
  quiet = TRUE)
knitr::opts_chunk$set(message = FALSE, warning = FALSE)
```

Some helper functions we will use later:
```{r helper-functions}
# utility to choose more or less interactively the line styles
surv_two_var_aes <- function(fit, data,
                             hue, # one var distinguished by distinct colours
                             palette = 'Set2', # selection of Brewer colours
                             idx = c(1,2),     # by colour number within palette
                             hue_direction = c("hot2cold", "cold2hot"), # order of colours
                             shade = var2, # other var distinguished by saturation and linetype
                             darkening=FALSE,
                             linetypes = c("solid", "longdash", "dashed", "dotted")) {
  
  if (!is.factor(data[[hue]]))   data[[hue]]   <- factor(data[[hue]])
  if (!is.factor(data[[shade]])) data[[shade]] <- factor(data[[shade]])
  hue_levels   <- levels(data[[hue]])      # reference = first
  shade_levels <- levels(data[[shade]])
  nh <- length(hue_levels)
  ns <- length(shade_levels)

  if (length(idx) != nh)
    stop("`idx` must have one index per `hue` level (", nh, "), got ", length(idx), ".")
  if (length(palette) == 1L) palette <- rep(palette, nh)
  if (length(palette) != nh)
    stop("`palette` must be length 1 (shared) or one per `hue` level (", nh, ").")
  if (ns > length(linetypes))
    stop("`shade` has ", ns, " levels but only ", length(linetypes), " linetypes.")

  hue_direction <- match.arg(hue_direction)

  linetype_combos <- list(
    '2' = linetypes[c(1,4)],
    '3' = linetypes[c(1,3,4)],
    '4' = linetypes
  )

  ## base colours → borrow hue and value per hue level
  base_cols <- vapply(seq_len(nh),
                      function(i) brewer.pal(8, palette[i])[idx[i]], character(1))
  if (length(base_cols) != length(unique(base_cols)))
    stop("you have repeated hues - please check the `palette` and `idx` arguments")

  hsvb  <- rgb2hsv(col2rgb(base_cols))         # rows: h, s, v
  if(hue_direction=="hot2cold") {
    hsvb <- hsvb[, order(hsvb["h", ])]
    } else {
    hsvb <- hsvb[, rev(order(hsvb["h", ]))]
    }
  H_lev <- setNames(hsvb["h", ], hue_levels)   # hue   per hue level
  V_lev <- setNames(hsvb["v", ], hue_levels)   # VALUE per hue level (fixed)

  ## saturation: half-of-max → max, across shade levels
  s_max <- max(hsvb["s", ])
  svals <- if(ns == 1L) { s_max } else {seq(s_max / 2, s_max, length.out = ns)}
  if (!darkening) svals <- rev(svals)          # FALSE → reference is most saturated
  names(svals) <- shade_levels

  ## linetype follows saturation: least saturated = solid, most = dotted
  lty_by_level <- linetype_combos[[as.character(ns)]]
  names(lty_by_level) <- shade_levels

  ## assemble in fit$strata order — value from hue, saturation from shade
  parts   <- strsplit(names(fit$strata), ", ", fixed = TRUE)
  get_val <- function(p, v) {
    pref <- paste0(v, "=")
    trimws(substring(p[startsWith(p, pref)], nchar(pref) + 1))
  }
  hl <- vapply(parts, get_val, character(1), v = hue)
  sl <- vapply(parts, get_val, character(1), v = shade)

  list(colours   = setNames(hsv(H_lev[hl], svals[sl], V_lev[hl]), names(fit$strata)),
       linetypes = setNames(unname(lty_by_level[sl]),            names(fit$strata)))
}

# utility to preview the hue/value/linetype choices:
preview_aes <- function(av, n_points = 50) {
  strata <- names(av$colours)
  n      <- length(strata)

  df <- do.call(rbind, lapply(seq_len(n), function(i) {
    x <- seq(0, 1, length.out = n_points)
    data.frame(
      x   = x,
      y   = (n - i) + 1 + (sample(-10:10, n_points, replace = TRUE) / 100),
      key = strata[i]
    )
  }))

  df$key <- factor(df$key, levels = strata)   # lock legend + curve order

  ggplot(df, aes(x, y, colour = key, linetype = key)) +
    geom_line(linewidth = 0.4) +
    scale_colour_manual(values   = av$colours) +
    scale_linetype_manual(values = av$linetypes) +
    scale_y_continuous(breaks = unique(df$y[df$x == 0]),
                       labels = strata) +
    labs(x = NULL, y = NULL, colour = "Stratum", linetype = "Stratum") +
    theme_classic(base_size = 5) +
    theme(legend.position = "right")
}

# to beautify the legends
surv_split_legend <- function(g, fit, av, hue, shade,
                              hue_labels = NULL, shade_labels = NULL,
                              hue_title = hue, shade_title = shade) {

  ## parse "genotype=wild-type, treatment=mock" → component levels -----------
  pick <- function(varname) {
    parts <- strsplit(names(fit$strata), ", ", fixed = TRUE)
    pref  <- paste0(varname, "=")
    vapply(parts, function(x) substring(x[startsWith(x, pref)], nchar(pref) + 1),
           character(1))
  }
  geno <- pick(hue); trt <- pick(shade)

  ## one representative swatch per level (last occurrence = most saturated) --
  kg <- !duplicated(geno, fromLast = TRUE)
  kt <- !duplicated(trt,  fromLast = TRUE)
  hue_values <- setNames(av$colours[kg],   geno[kg])
  lty_values <- setNames(av$linetypes[kt], trt[kt])

  if (is.null(hue_labels))   hue_labels   <- names(hue_values)
  if (is.null(shade_labels)) shade_labels <- names(lty_values)

  ## NA-coord dummy layers: train the scale (→ legend keys) but draw nothing -
  dg <- data.frame(x = NA_real_, y = NA_real_,
                   .g = factor(names(hue_values), levels = names(hue_values)))
  dt <- data.frame(x = NA_real_, y = NA_real_,
                   .t = factor(names(lty_values), levels = names(lty_values)))

  g$plot <- g$plot +
    guides(colour = "none", linetype = "none") +          # kill merged legend
    ## genotype → colour
    new_scale_colour() +
    geom_line(data = dg, aes(x, y, colour = .g), na.rm = TRUE) +
    scale_colour_manual(name = hue_title, values = hue_values, labels = hue_labels,
                        guide = guide_legend(order = 1,
                          override.aes = list(linetype = "solid", linewidth = 1.4))) +
    ## treatment → linetype
    new_scale("linetype") +
    geom_line(data = dt, aes(x, y, linetype = .t), colour = "grey20", na.rm = TRUE) +
    scale_linetype_manual(name = shade_title, values = lty_values, labels = shade_labels,
                          guide = guide_legend(order = 2,
                            override.aes = list(colour = "grey20", linewidth = 0.7))) +
    theme(legend.text = element_markdown(), legend.title = element_markdown())

  g
}

# to beatify the legends
strata_labels <- function(fit, delim = ' | ', subs = NULL) {
    ## "genotype=wild-type, treatment=mock" -> "wild-type, mock"
    lab <- gsub("[^=,]+=", "", names(fit$strata))
    lab <- trimws(gsub(",", delim, lab))
    if (!is.null(subs))                       # apply any markup swaps, e.g. mfg[1]
        for (from in names(subs))
            lab <- gsub(from, subs[[from]], lab, fixed = TRUE)
    lab
}
```

### Survival analysis

We are not statisticians, so the analyses illustrated here are not very
sophisticated. However, you should be somewhat familiar with:

- [Kaplan-Meier](https://rmvpaeme.github.io/KaplanMeier_intro/) [(KM) plots](https://pmc.ncbi.nlm.nih.gov/articles/PMC5045282/pdf/jadp-07-091.pdf)

- [Cox-proportional hazards (CPH) modelling](http://www.sthda.com/english/wiki/cox-proportional-hazards-model)

- and [CPH model assumptions](http://www.sthda.com/english/wiki/cox-model-assumptions)

There are plenty of resources online that explain at different levels of
expertise what these are and how to interpret them. Some reasonable resources are:

- STHDA's [_Survival Analysis Basics_](https://www.sthda.com/english/wiki/survival-analysis-basics)
and [_Survival Analysis_](https://www.sthda.com/english/wiki/survival-analysis)
guides.

- TDV Swinscow's [_Statistics at Square One_ at the BJM](https://www.bmj.com/about-bmj/resources-readers/publications/statistics-square-one)
But, in a nutshell, KM plots are used to estimate and visualise survival distributions. Log-rank tests can tell you whether two or more of these distributions are significantly different, but not by how much nor is suitable for more than pair-wise comparisons. CPH modelling can also test for significance but also it can (1) compare multiple distributions at time and (2) _quantify the size of the effect_. However, this is only informative if the assumptions of the CPH model hold.

- The four-part tutorial on survival analysis by [MJ Bradburn, TG Clark, SB Love and DG Altman in the British Journal of Cancer](https://www.nature.com/bjc/articles?type=tutorial-paper&year=2003)

Our steps will be:

- Load the data and demonstrate how to do additional cleanup, if needed.

- Check for equal distribution of replicates within each cohort and decide whether outlier replicates should be eliminated.

- Plot KM graphs to visualise survival distributions.

- Perform CPH modelling for replicates, experimental variables and their interactions.

- Check that the assumptions of the CPH model hold.

## 4B. Initial inspection of the data

### Loading the data

The [last (3^rd^) Jupyter python notebook](./03_Read_DataSheets.html) produces an XLSX file whose `Observ_m2c_atStart_analysis` spreadsheet will contain the events (deaths, censorings) ready for analysis with _survival_ in the form:

 Day_no. | Rack_no. | Tube_no. | genotype | treatment | Event
---------|----------|----------|----------|-----------|------------
    1    |     1    |    1     | wild-type|    mock   | 1 _(death)_
    1    |     1    |    2     | wild-type|    mock   | 0 _(censor)_

You will find this file in:
```
your-home-directory/
 └──Drosben_userdata/
    └──experiments_data/
       └──02.02.2022_Effect-of-myfavouritegene-on-lifespan_bd8b2f79/
          └──bd8b2f79_observations.xlsx
```

In principle we can simply find this automatically but if this is not possible, you will be able to find it interactively:
```{r load-data,  message = FALSE, warning = FALSE}
filepath <- file.path(
  path.expand("~"),
  "Drosben_userdata", "experiments_data",
  "02.02.2022_Effect-of-myfavouritegene-on-lifespan_bd8b2f79",
  "bd8b2f79_observations.xlsx"
)
if (!file.exists(filepath)) filepath <- file.choose()

survdata <- read_excel(filepath, sheet = 'Observ_m2c_atStart_analysis')
kbl(head(survdata)) %>%
  kable_styling(full_width = FALSE) %>%
  column_spec(1:ncol(survdata), width = "8em")
```
The column names of this dataframe are fixed, except for the variable names, which are decided by the user in the [first Jupyter noteboook](./01_First_Use_Colour_Calibration.html). We could obtain them from the `experimentID_infodict.xlsx` file, but it is easier to do:
```{r colnames}
fixed_colnames <- c("Day_no.", "Rack_no.", "Tube_no.", "Event")
varnames <- setdiff(colnames(survdata), fixed_colnames)
var1 <- varnames[[1]]
var2 <- varnames[[2]]
varnames
```

In the example, the specimens are organised like this:

Stratum no. | Variable levels   | Rack_no. | Tube_nos. | Replicates
------------|-------------------|----------|-----------|----------------------
     1      |wild-type, mock    |     1    |    1-12   | rack 1, tubes 1 - 12
     2      | _mfg^1^_, mock    |     2    |    1-12   | rack 2, tubes 1 - 12
     3      |wild-type, treated |     3    |    1-12   | rack 3, tubes 1 - 12
     4      | _mfg^1^_, treated |     4    |    1-12   | rack 4, tubes 1 - 12

So, the replicate could be equated to the `Tube_no.`.
However, the user has the flexibility to organise this in any other way, for instance:

Stratum no. | Variable levels   | Rack_no. | Tube_nos. | Replicates
------------|-------------------|----------|-----------|----------------------
     1      |wild-type, mock    |     1    |    1-6    | rack 1, tubes 1 - 6
     1      |wild-type, mock    |     2    |    1-6    | rack 2, tubes 1 - 6
     2      | _mfg^1^_, mock    |     1    |    7-12   | rack 1, tubes 7 - 12
     2      | _mfg^1^_, mock    |     2    |    7-12   | rack 2, tubes 7 - 12
     3      |wild-type, treated |     3    |    1-6    | rack 3, tubes 1 - 6
     3      |wild-type, treated |     4    |    1-6    | rack 4, tubes 1 - 6
     4      | _mfg^1^_, treated |     3    |    7-12   | rack 3, tubes 7 - 12
     4      | _mfg^1^_, treated |     4    |    7-12   | rack 4, tubes 7 - 12

Or even more complicated arrangements, like each Stratum occupying 3 tubes in each of the 4 racks—maybe not even the same tube numbers in each rack. To ensure _any_ arrangement of replicates (the distinct physical tubes) is captured, we do:
```{r clean-colnames,  message = FALSE, warning = FALSE}
rep_key <- survdata %>%
  distinct(.data[[var1]], .data[[var2]], `Rack_no.`, `Tube_no.`) %>%
  arrange(.data[[var1]], .data[[var2]], `Rack_no.`, `Tube_no.`) %>%
  group_by(.data[[var1]], .data[[var2]]) %>%
  mutate(replicate = row_number()) %>%
  ungroup()

survdata <- survdata %>%
  left_join(rep_key, by = c(var1, var2, "Rack_no.", "Tube_no.")) %>%
  select(!c(`Rack_no.`, `Tube_no.`)) %>%
  rename(
    event = Event,
    day   = `Day_no.`)

kbl(head(survdata)) %>%
  kable_styling(full_width = FALSE) %>%
  column_spec(1:ncol(survdata), width = "8em")
```

Finally, we need to define which variable conditions are our reference (controls):
```{r set-reference-lvls}
survdata[[var1]] <- factor(survdata[[var1]], levels = c('wild-type', 'mfg[1]'))
survdata[[var2]] <- factor(survdata[[var2]], levels = c('mock', 'treated'))
```

### Analysis of replicates

To ensure consistency of behaviour of within replicates, we subset the data:

```{r replicates}
# replicate as a factor → discrete colours + a clean legend
levels <- as.character(sort(unique(as.integer(as.character(survdata$replicate)))))
survdata$replicate <- factor(survdata$replicate, levels = levels)

fit <- survfit(Surv(time = day, event = event) ~ replicate, data = survdata)

g <- ggsurvplot_facet(
  fit, survdata,
  facet.by      = c(var1, var2),   # one panel per stratum (var1/var2 are strings)
  axis.labels   = "all",
  color         = "replicate",     # colour each replicate to spot outliers
  conf.int      = FALSE,           # keep curves clean, like the base-R version
  censor        = TRUE,            # + censoring marks
  break.time.by = 20,              # tick spacing, echoing axis(seq(10,90,20))
  xlab          = "Lifespan (days)",
  ylab          = "Survival probability",
  short.panel.labs = TRUE,         # panel strips show just the level
  ggtheme       = theme_classic()  # minimal, base-R-like: axis lines, no grid
) +
  # to control the order of colours and replicate number
  scale_colour_manual(
    values = brewer.pal(12, "Paired"),
    name   = "Replicate",
    limits = levels,
    breaks = levels
  ) +
  # to plot internal XY axes
 facet_grid(
  rows = vars(.data[[var1]]),
  cols = vars(.data[[var2]]),
  axes        = "all",
  axis.labels = "margins"
)

g
```

From this, we might want to remove replicate #2 of the _mfg^1^_, mock stratum, as there is full mortality beforre day 40. However, this is likely due to a large amount of censoring at around day 20, followed by the death of one or two individuals left in the tube (see [Jupyter notebook #3](./03_Read_DataSheets.html), section 3C). This will likely have no impact on the final result, but we might just as well eliminate this replicate:
```{r replicate-filter}
survdata_filt <- survdata %>%
  filter_out(.data[[var1]]=='mfg[1]' & .data[[var2]]=='mock' & replicate==2)

fit <- survfit(Surv(time = day, event = event) ~ replicate, data = survdata_filt)

g <- ggsurvplot_facet(
  fit, survdata_filt,
  facet.by      = c(var1, var2),   # one panel per stratum (var1/var2 are strings)
  axis.labels   = "all",
  color         = "replicate",     # colour each replicate to spot outliers
  conf.int      = FALSE,           # keep curves clean, like the base-R version
  censor        = TRUE,            # + censoring marks
  break.time.by = 20,              # tick spacing, echoing axis(seq(10,90,20))
  xlab          = "Lifespan (days)",
  ylab          = "Survival probability",
  short.panel.labs = TRUE,         # panel strips show just the level
  ggtheme       = theme_classic()  # minimal, base-R-like: axis lines, no grid
) +
  scale_colour_manual(
    values = brewer.pal(12, "Paired"),
    name   = "Replicate",
    limits = levels,
    breaks = levels
  ) +
 facet_grid(
  rows = vars(.data[[var1]]),
  cols = vars(.data[[var2]]),
  axes        = "all",
  axis.labels = "margins"
)

g
```
While replicates #1 for both treatments in _mfg^1^_ individuals seem to be outliers, they are not fundamentally different and we will keep them.

## 4C. Effect on survival of `r var1`, `r var2`

### Basic Kaplan-Meier plot with log-rank testing

We want now to plot `r var1` and `r var2` in two colourblind-friendly hues (i.e. blue and orange) with each level on different lightness/linetype. We can choose colours from the `RColorBrewer` palettes:

```{r show-RColorBrewer-palettes, echo=FALSE, fig.height=3, fig.width=2}
par(cex = 0.5)
display.brewer.all(colorblindFriendly = TRUE)
```

I will use colour #2 from Set2 as my orange and colour #2 from Paired as my blue, for the genotypes, and I will use shading and linetype to distinguish treatments:

```{r set-line-aes, fig.width=3, fig.height=0.5}
# to keep the code generic, instead of writing the formula as
# Surv(day, event) ~ genotype + treatment
# we can use `glue`:
gluedformula <- as.formula(glue("Surv(day, event) ~ {var1} + {var2}"))
# this way the code could run with more than just the example data
fit <- surv_fit(formula = gluedformula,
               data = survdata_filt)
S <- surv_two_var_aes(fit, survdata_filt,
                      hue   = var1, # genotypes distinguished by distinct colours
                      palette = c('Set2', 'Paired'), # selection of Brewer colours
                      idx = c(2,2),                  # by colour number within palette
                      hue_direction = "cold2hot", # order of colours
                      shade = var2, # treatments distinguished by saturation and linetype
                      darkening=TRUE)

p <- preview_aes(S, n_points=7)
p + theme(legend.key.height = unit(0.02, "cm"))
```

These combinations seem easy to discriminate, so we can now plot the 4 survival curves:

```{r plot-to-save, cache = FALSE, message = FALSE, warning = FALSE}
# specific for the example dataset >>>
subs <- c("mfg[1]" = "_mfg_<sup>1</sup>")               
legendlabs <- strata_labels(fit, delim=' | ', subs = subs)
title <- 'Survival effects of _mfg^1^_ and _treatment_' # specific for the example dataset
# <<< specific for the example dataset

g <- ggsurvplot(fit, survdata_filt,
                pval = TRUE,                       # adds pval
                pval.coord = c(-3, 0.05),
                censor = TRUE,                     # adds censorings
                censor.shape = 124,                # censorings represented with '|'
                conf.int = TRUE,                   # adds 95% confidence interval
                conf.int.alpha = 0.1,              # makes it more transparent
                surv.median.line = "hv",           # adds median points
                palette  = unname(S$colours),
                linetype = unname(S$linetypes),
                xlab = "Time (days)",              # remove x axis label
                ylab = "Survival probability",     # y axis label
                font.legend = c(8),                # legend size
                legend = "bottom",                 # legend position
                
                title = title,           # comment or change for your own data
                legend.labs = legendlabs # comment or change for your own data
)

g$plot <- g$plot + # specific layering for ggsurvplot
  guides(colour = guide_legend(ncol = 1), linetype = guide_legend(ncol = 1)) +
  theme(plot.title = element_markdown(face = 'bold', size=18),
        axis.title.x = element_text(face = 'bold', size=16),
        axis.title.y = element_text(face = 'bold', size=16),
        axis.text.x = element_text(face = 'bold', size=13),
        axis.text.y = element_text(face = 'bold', size=13),
        axis.line = element_line(colour = 'black', size = 0.7),
        axis.ticks = element_line(colour = "black", size = 0.7),
        legend.text = element_markdown(),
        legend.title = element_blank(),
        legend.position = "inside",
        legend.position.inside = c(0.85, 0.8))
g
ggsave(
  'km_basic.pdf',
  plot = get_last_plot(),
  dpi = 300)
```

From this, it is clear that the treatment seems to have no effect, or very little (and positive) on the wild-types, but a very strong effect on the _mfg^1^_ mutants. However, the untreated _mfg^1^_ mutants also seem to have a higher mortality than wild-types. The compound effect of mutation and treatment does not seem additive, but this analysis cannot tell us whether there is an interaction between genotype and treatment (i.e. whether the treatment is detrimental _specifically_ for _mfg^1^_ flies).

The p-value indicated in the figure is from a log-rank test, which only tells us whether, of the 4 survival curves, at least one is significantly different. If we wanted more detail (e.g. are untreated mutants less longevous than untreated controls?), we would need to do paired log-rank tests.

However, if the assumptions of the Cox Proportional Hazards model were respected, this modelling would be far more informative, as we could ask for variable interactions.

### Cox Proportional Hazards modelling

To test whether our data respect the assumption of proportional hazards, first we need to build the model itself, so we might just as well evaluate the model first and check after whether it is solid.

For this, we simply change the generic modelling produced by `survival::survfit` or `survminer::surv_fit` for `survival::coxph`. This approach allow us to obtain the _Hazard Ratios_ (HR) for each of the significant conditions, and their p-values:
```{r cph-gtsummary, cache = FALSE, message = FALSE, warning = FALSE}
gluedformula <- as.formula(glue("Surv(day, event) ~ {var1} * {var2}"))
# `~ var1 * var2` expands to `~ var1 + var2 + var1:var2`
phfit <- coxph(formula = gluedformula,
               data = survdata_filt)
tbl_regression(phfit,
               exponentiate = TRUE,
               pvalue_fun = ~ format.pval(.x, digits = 1, eps = 1e-16)
) %>% bold_p()
```

We can also obtain explicitly the median survival for each experimental stratum:

```{r median-lifespans, cache = FALSE, message = FALSE, warning = FALSE}
medians <- summary(fit)$table[, "median"]
medians <- data.frame(names = names(medians),
                      medians = unname(medians))
medians <- medians %>%
  mutate(conditions = str_replace_all(names, "[^=,]+=", "")) %>%
  mutate(conditions = str_replace(conditions, ",", " | ")) %>%
  mutate(conditions = trimws(conditions)) %>%
  select(!names)
kbl(medians) %>%
  kable_styling(full_width = FALSE) %>%
  column_spec(1:ncol(medians), width = "10em")
```

All this confirms that:

- _mfg^1^_ mutants are significantly (p=0.007) less long lived (~8% shorter median lifespan, and 1.4 hazard ratio)

- the treatment specifically affects _mfg^1^_ mutants, which reduce their median lifespan a _further_ 43%, and have a hazard ratio (respect to untreated wild-types) of 7.2.

The hazard ratio is not as intuitive as the median lifespan as a measure of the strength of the effect, but it is far more precise. Each condition's hazard is like the decay rate of a radioactive isotope — the instantaneous _rate_ at which survivors are "lost" — except that an isotope's decay rate is constant, but death rates (mortality) tend to increase with age in most organisms, and _Drosophila_ is no exception. So, the 'half-life' of a fly is reduced with age. The hazard ratio is simply how many times faster one condition decays than the other, and the model assumes that multiple stays constant across the lifespan (the _proportional hazards_ assumption) even as the underlying rate (for the reference condition) climbs (in whichever temporal pattern).

In any case before continuing we need to check the model assumptions.

### Test for proportional hazards

The Schoenfeld residuals test is the diagnostic tool to assess whether the proportional hazards assumption is respected:

```{r schoenfeld-test, cache = FALSE, message = FALSE, warning = FALSE}
model_zph<-cox.zph(phfit)
model_zph$table %>%
  kbl(digits = c(2, 0, 3)) %>%
  kable_styling(full_width = FALSE) %>%
  column_spec(1, width = "10em") %>%
  column_spec(2:4, width = "8em")
```

Here, the null hypothesis is that the assumption is not respected, so a significant p-value indicates a violation of the assumption. The results indicate that the assumption is **not respected** for the compound effect of the treatment and the _mfg^1^_ mutation.

We can have a graphical inspection of why this may be the case looking at the Schoenfeld residuals plots:

```{r schoenfeld-residuals, cache = FALSE, message = FALSE, warning = FALSE, fig.height=9, fig.width=6}
ggcoxzph(model_zph)
```

These plots show how the residuals in the interaction term are not following the expectation. This does not mean that all the conclusions from the CoxPH model are invalid - the fact that there is an interaction between genotype and treatment can be seen by eye! However, the interpretation of the hazards ratio, for instance, needs to be taken as a timed average rather than a constant. The CoxPH model can be refined/extended considering the hazard ratio as a function of time, which in this case could probably resolve the problem. But this seems an overkill for this dataset (which is synthetic, anyway!).

---
END
---

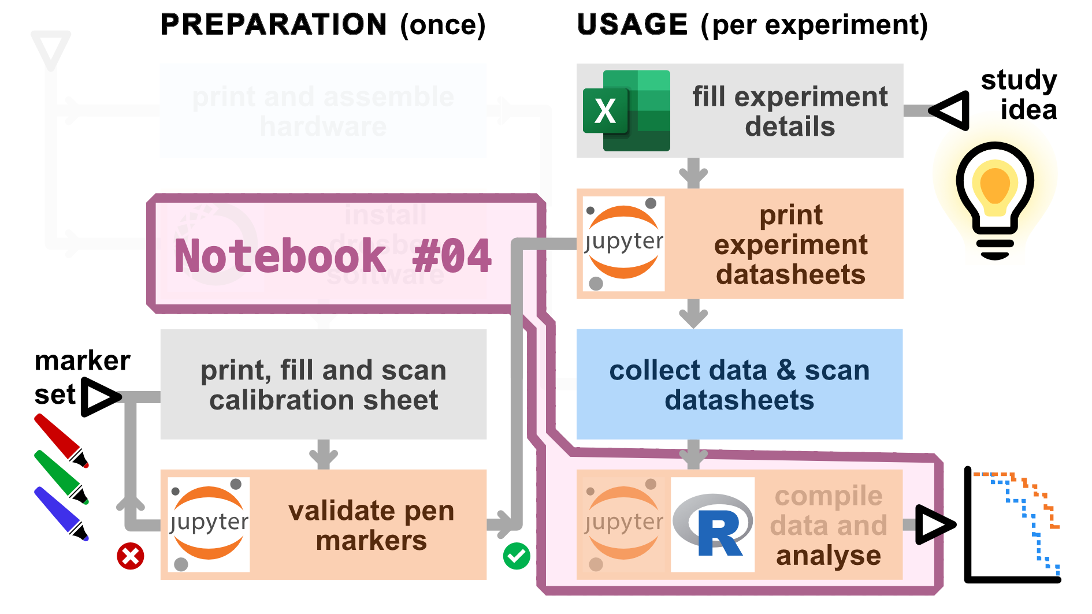
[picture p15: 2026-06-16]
docs/img/overview_soft4.png

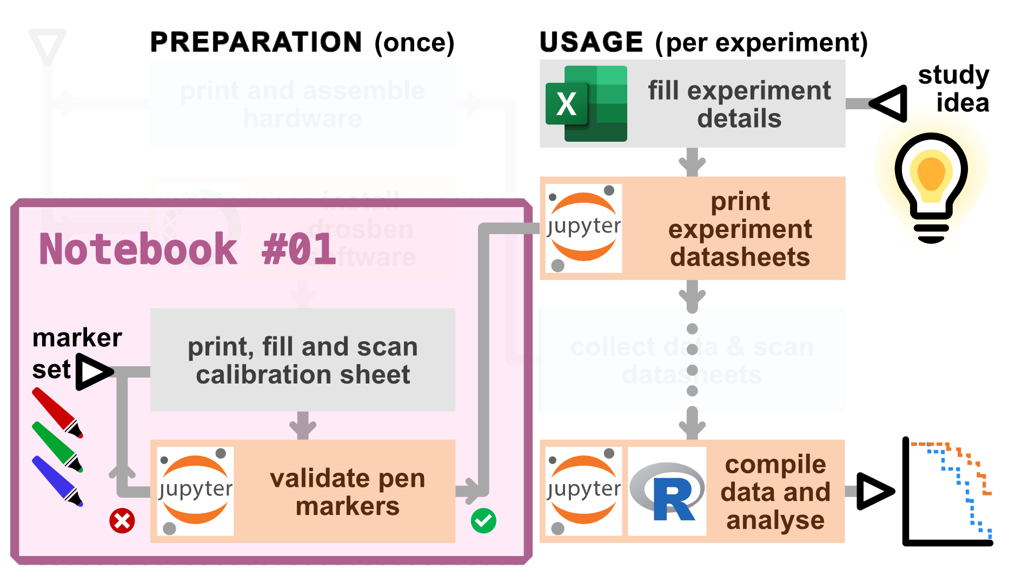
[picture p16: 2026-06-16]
docs/img/overview_soft1.png

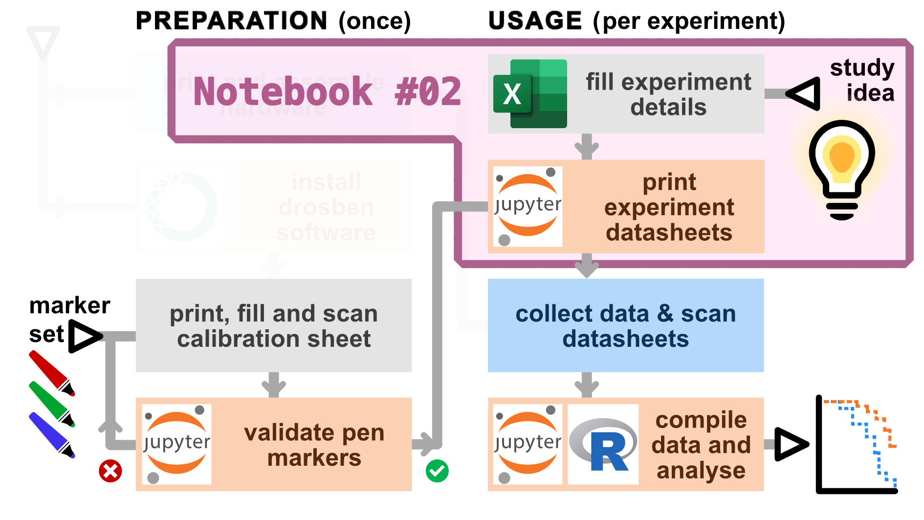
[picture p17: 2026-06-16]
docs/img/overview_soft2.png

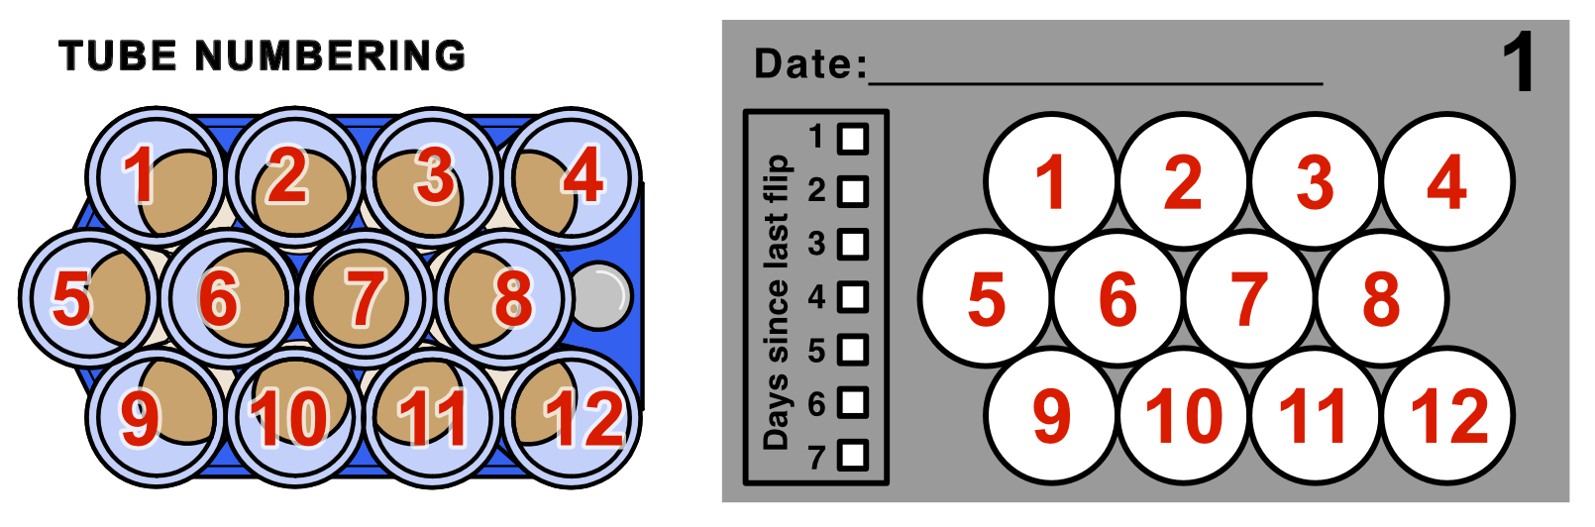
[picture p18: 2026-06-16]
docs/img/tube_numbering.png

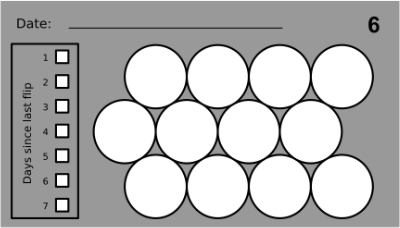
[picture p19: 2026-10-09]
docs/img/rack_area.png

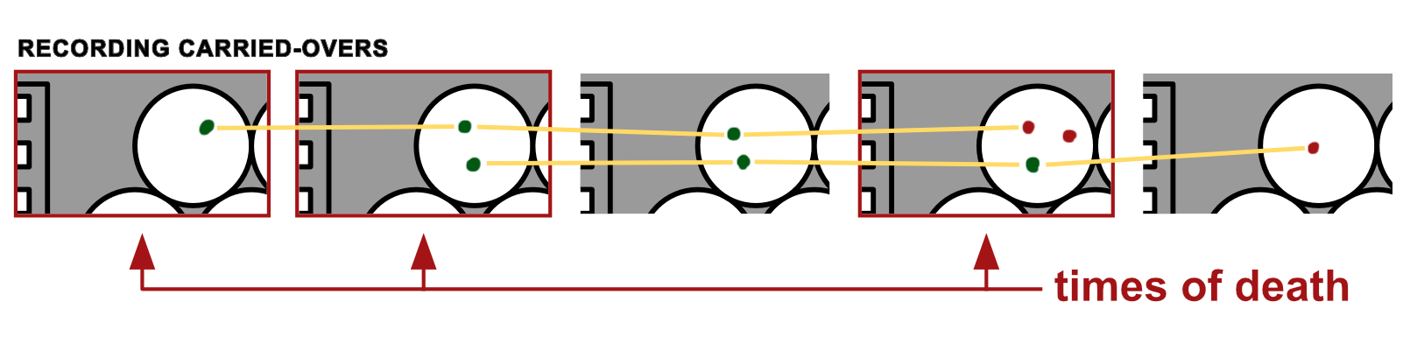
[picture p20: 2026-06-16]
docs/img/carried_overs.png

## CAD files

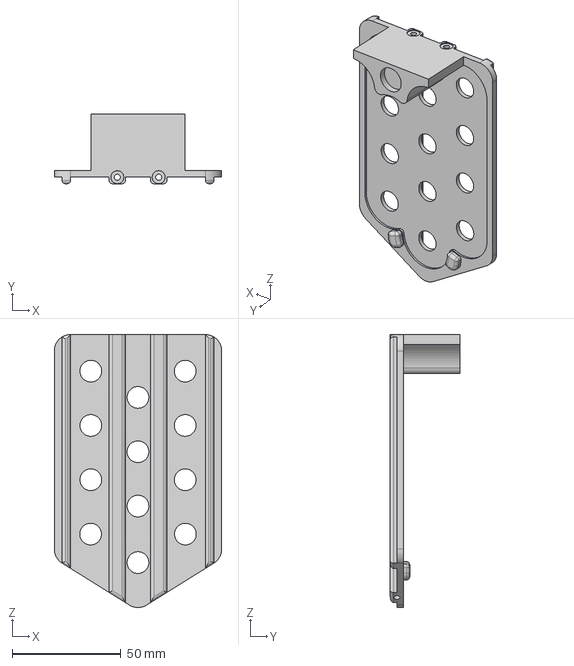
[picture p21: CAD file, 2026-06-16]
hardware/3D_models/Depositor/Depositor.step
77.0 x 32.0 x 125.6 mm

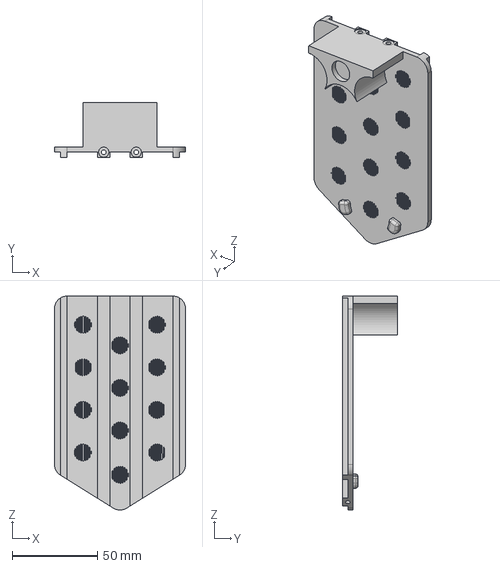
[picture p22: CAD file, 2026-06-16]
hardware/3D_models/Lid/Lid.stp
77.0 x 32.0 x 125.6 mm

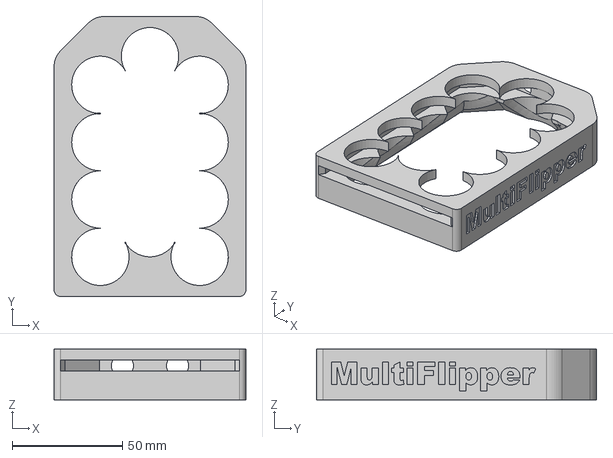
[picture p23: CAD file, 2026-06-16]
hardware/3D_models/Multiflipper/multiflipper.stp
87.0 x 127.0 x 23.0 mm

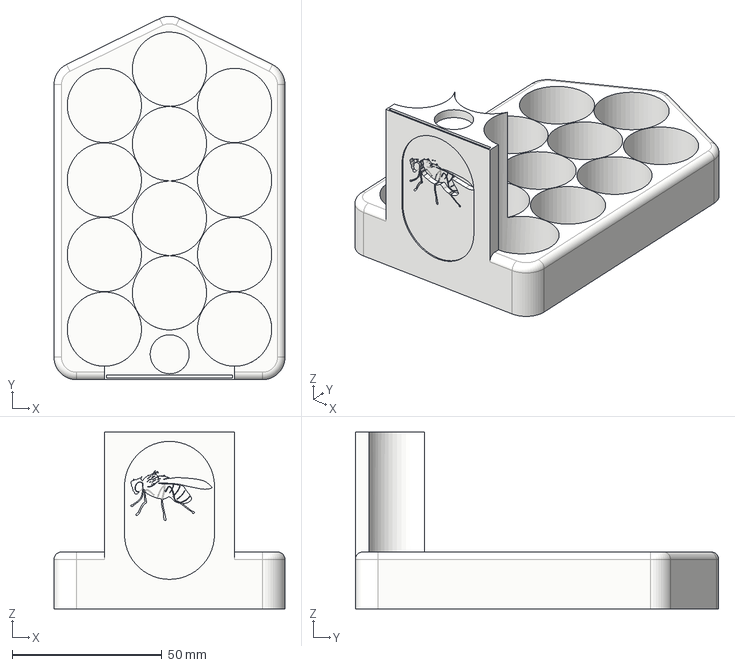
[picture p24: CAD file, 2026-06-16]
hardware/3D_models/Rack/Rack.stp
77.0 x 121.1 x 59.0 mm

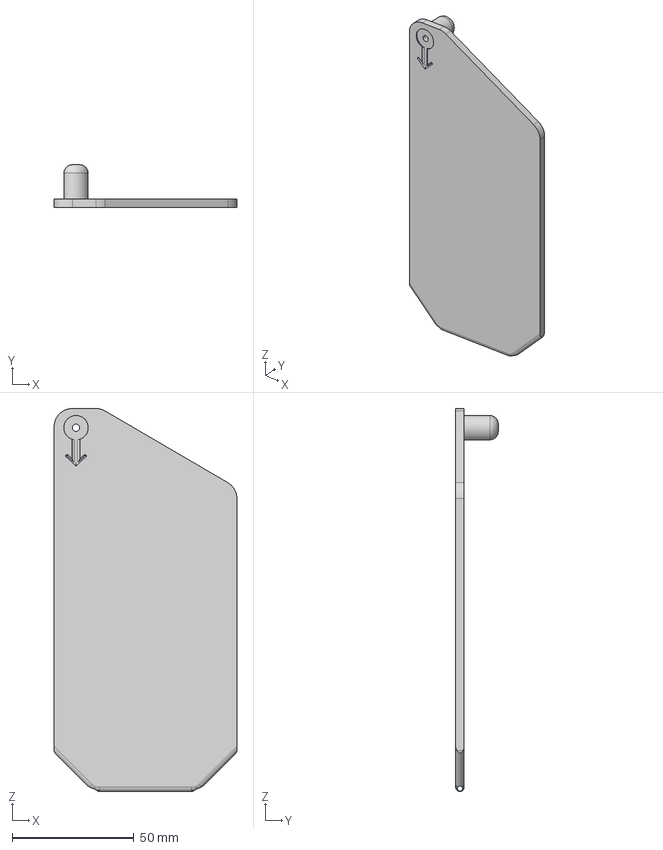
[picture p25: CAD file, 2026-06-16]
hardware/3D_models/Slider/Slider.stp
75.0 x 17.5 x 157.1 mm

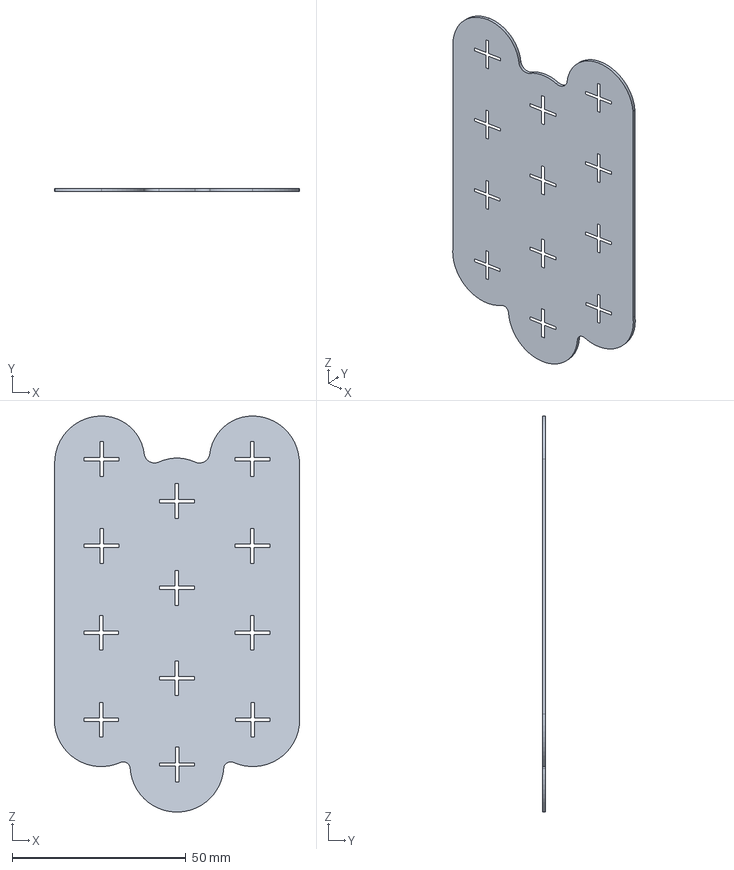
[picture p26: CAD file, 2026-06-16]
hardware/3D_models/Utilities/Depositor_stencil.FCStd
70.6 x 1.00 x 114.0 mm

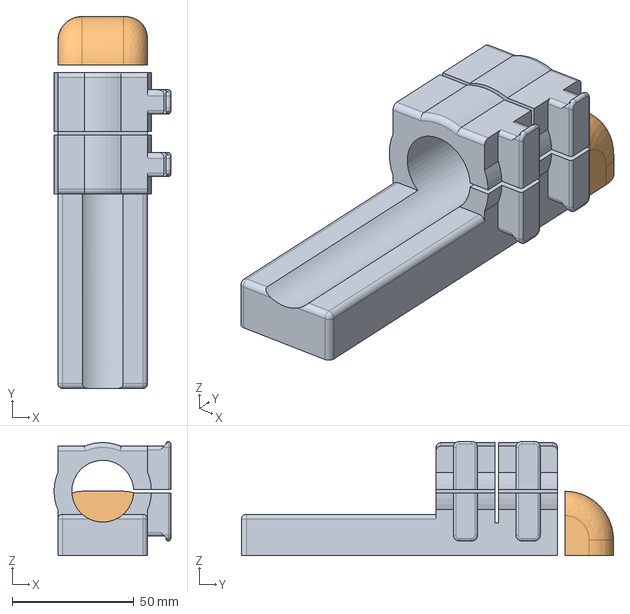
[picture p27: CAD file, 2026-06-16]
hardware/3D_models/Utilities/tube_cutter_reference.step
48.0 x 153.0 x 47.0 mm

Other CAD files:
hardware/3D_models/Depositor/Depositor.3mf
hardware/3D_models/Depositor/Depositor.FCStd
hardware/3D_models/Depositor/Depositor.stl
hardware/3D_models/Lid/Lid.3mf
hardware/3D_models/Lid/Lid.FCStd
hardware/3D_models/Lid/Lid.stl
hardware/3D_models/Multiflipper/multiflipper.3mf
hardware/3D_models/Multiflipper/multiflipper.FCStd
hardware/3D_models/Multiflipper/multiflipper.stl
hardware/3D_models/Rack/Rack.3mf
hardware/3D_models/Rack/Rack.FCStd
hardware/3D_models/Rack/Rack.stl
hardware/3D_models/Slider/Slider.3mf
hardware/3D_models/Slider/Slider.FCStd
hardware/3D_models/Slider/Slider.stl
hardware/3D_models/Utilities/Depositor_stencil.3mf
hardware/3D_models/Utilities/Depositor_stencil.stl
hardware/3D_models/Utilities/tube_cutter_reference.3mf
hardware/3D_models/Utilities/tube_cutter_reference.FCStd
hardware/3D_models/Utilities/tube_cutter_reference.stl

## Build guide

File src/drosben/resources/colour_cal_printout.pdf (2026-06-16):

## Colour Testing

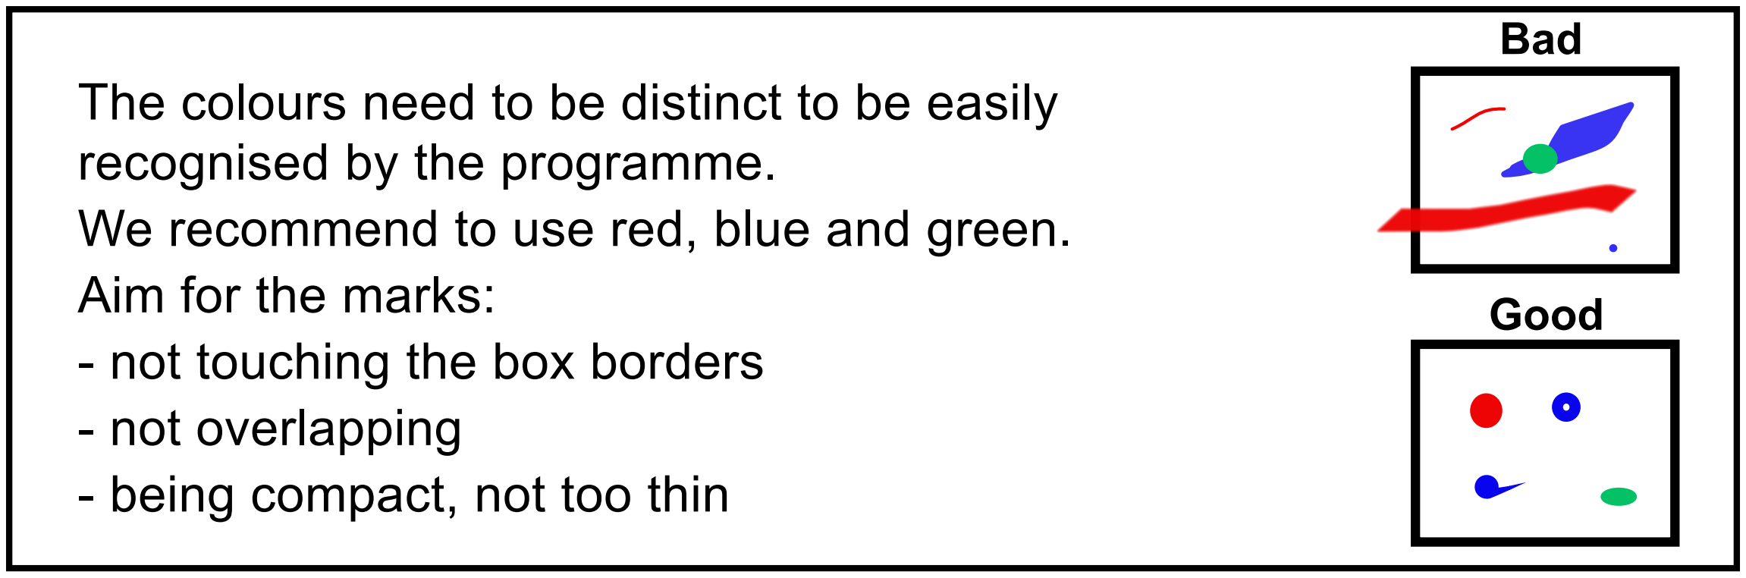
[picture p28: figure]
Bad; Good; recognised by the programme.; Aim for the marks: - not touching the box borders - not overlapping - being compact, not too thin

### 5 marks per box with the THIRD marker (recommended green):

7 | 8 | 9
| Five marks of each colour

10

### 5 marks per box with the FIRST colour marker (recommended red):

1 | 2 | 3

### 5 marks per box with the SECOND marker (recommended blue):

4 | 5 | 6

Scan the filled page at ≥150 d.p.i. and run the colour calibration test

The colours need to be distinct to be easily

We recommend to use red, blue and green.

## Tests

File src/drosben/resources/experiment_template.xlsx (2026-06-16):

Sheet: Metadata
key | value | Notes
exp_name |  | Experiment name (free text, but keep it under 40 characters)
init_date |  | Initial date of the experiment (DD.MM.YYYY, strictly in this format)
anon |  | Anonymised (whether to produce labels for conducting a blind study, TRUE/FALSE for Yes/No)
max_expec_lfspn |  | Maximum expected lifespan (in days, 200 is suggested)
fpw |  | Flips per week (1–7, usually 3)

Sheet: Variables
var | name | lvl1 | lvl2 | lvl3 | lvl4 | Notes
var1 |  |  |  |  |  | Variables 1 and 2 can be anything: genotype and treatment are the commonest combination. Fill in the relevant levels - those left blank will be ignored. Max 21 characters.
var2 |  |  |  |  |  | Most experiments will just have a few arms - we allow up to 8, but more complex scenarios would require setting up multiple drosben Experiments and dedicated data analysis.
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

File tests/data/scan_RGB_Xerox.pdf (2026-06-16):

## Colour Testing

'.1/

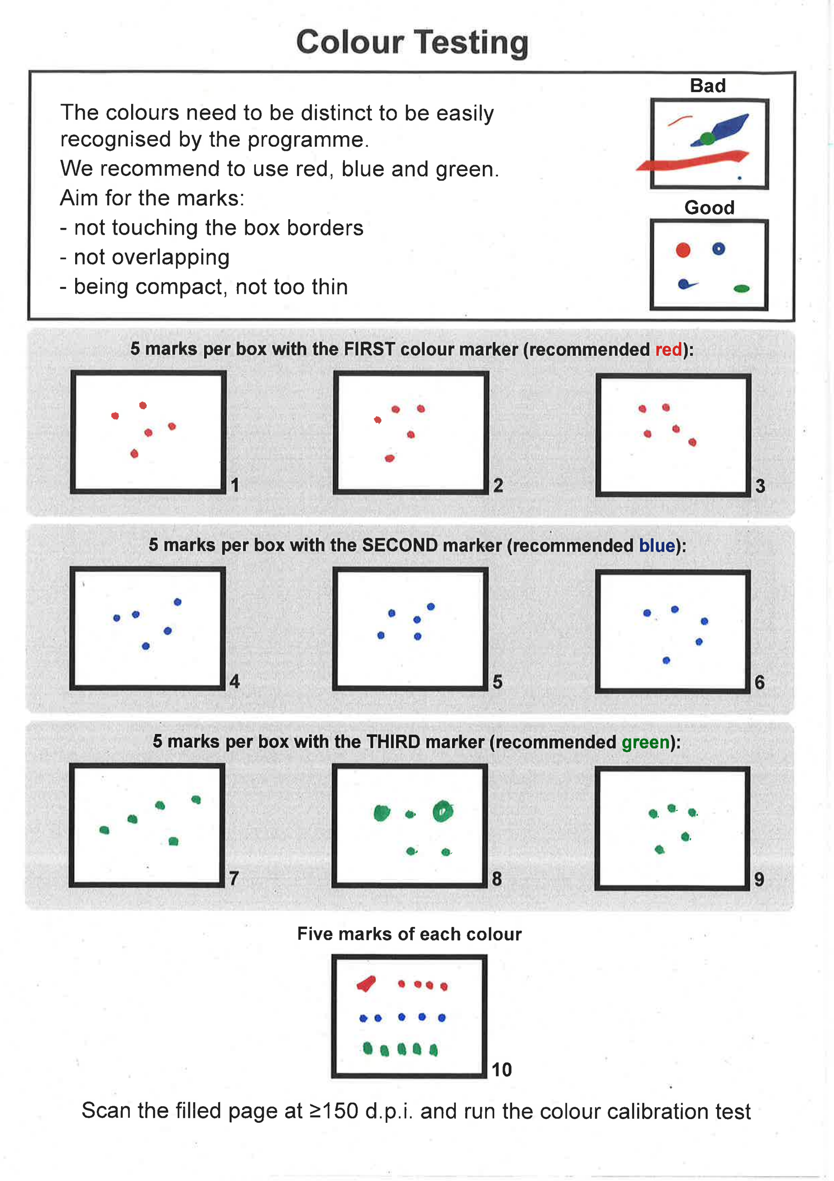
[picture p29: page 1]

The colours need to be distinct to be easily recognised by the programme.
We recommend to use red, blue and green. Aim for the marks:
- not touching the box borders
- not overlapping
- being compact, not too thin

Bad

Good

e (D

oo

t I

I

I

a

t t t
I
a

5 marks per box with the FIRST colour marker (recommended red):

5 marks per box with the SECOND marker (recommended blue):

5 marks per box with the THIRD marker (recommended green):

Five marks of each colour

1 | 3

10

a t I

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
at | I
| a

t t
a
Õe | ) ô,ø
| a, ¡.

t, l' t.

a, I

### a ¡ .r r

lO t a .l

## lrtrt

Scan the filled page at >150 d.p.i. and run the colour calibration test

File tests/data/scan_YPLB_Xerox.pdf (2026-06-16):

## Golour Testing

'-l/

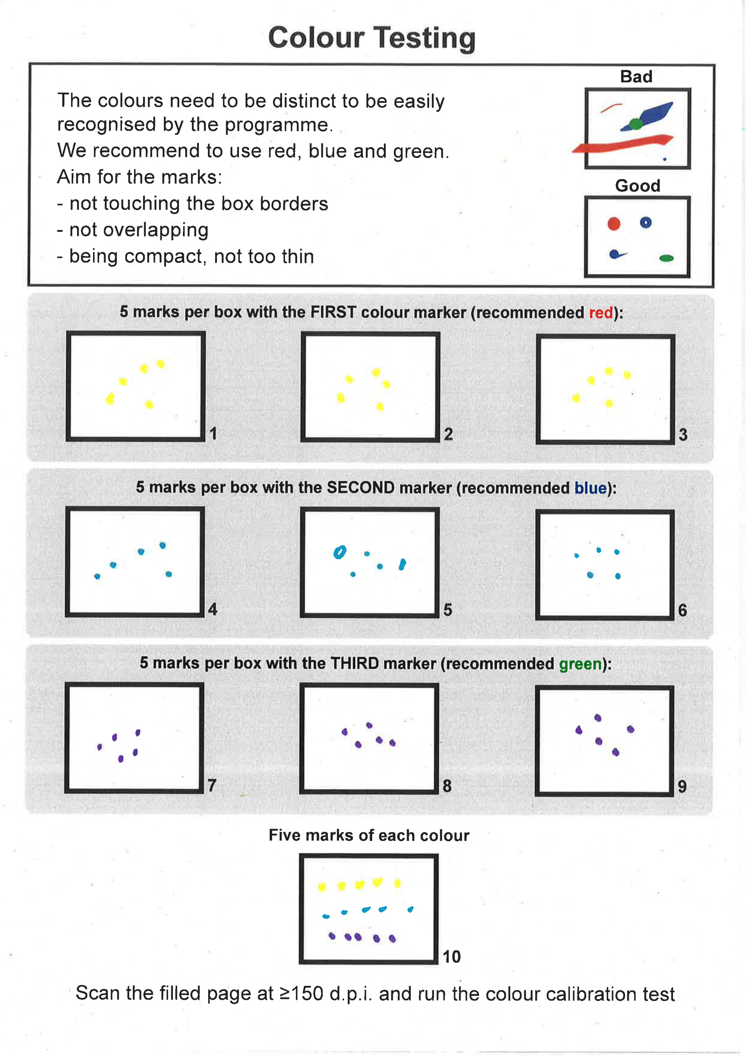
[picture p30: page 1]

The colours need to be distinct to be easily recognised by the programme.
We recommend to use red, blue and green. Aim for the marks:
- not touching the box borders
- not overlapping
- being compact, not too thin

Bad

Good

(D

oo

5 marks per box with the FIRST colour marker (recommended red):

5 marks per box with the SECOND marker (recommended blue):

5 marks per box with the THIRD marker (recommended green):

Five marks of each colour

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
t lt | I | t
I

t
I
i¡ t | eO | O
rrttt

Scan the filled page at à150 d.p.i. and run the colour calibration test

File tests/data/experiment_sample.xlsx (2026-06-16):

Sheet: Metadata
key | value | Notes
exp_name | Effect of myfavouritegene on lifespan | Experiment name (free text, but keep it under 40 characters)
init_date | 02.02.2022 | Initial date of the experiment (DD.MM.YYYY, strictly in this format)
anon | TRUE | Anonymised (whether to produce labels for conducting a blind study, TRUE/FALSE for Yes/No)
max_expec_lfspn | 100 | Maximum expected lifespan (in days, 200 is suggested)
fpw | 3 | Flips per week (1–7, usually 3)

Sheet: Variables
var | name | lvl1 | lvl2 | lvl3 | lvl4 | Notes
var1 | genotype | wild-type | mfg[1] |  |  | Variables 1 and 2 can be anything: genotype and treatment are the commonest combination. Fill in the relevant levels - those left blank will be ignored. Max 21 characters.
var2 | treatment | mock | treated |  |  | Most experiments will just have a few arms - we allow up to 8, but more complex scenarios would require setting up multiple drosben Experiments and dedicated data analysis.
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

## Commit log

2026-06-16 transfer materials after repo name change
    [Depositor.step, Depositor_stencil.3mf, Depositor_stencil.FCStd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]
2026-07-01 Expand assembly instructions in README.md
    Added detailed assembly instructions for Drosben components including materials needed and specific steps for each part.
2026-07-01 Revise 3D printing details in README.md
    Updated slicing and printing details for clarity.
2026-07-02 Enhance README with component and cost details
    Added detailed cost breakdown for components, materials, recipes, and tools in the README.
2026-07-02 added depositor file versions
    [Depositor.3mf, Depositor.FCStd, Depositor.stl]
2026-07-02 Update glue description in README
    Clarified the preferred presentation of cyanoacrylate glue in the materials list.
2026-07-02 Enhance README with rack building instructions
    Added detailed instructions for building racks, including printing settings and post-printing modifications.
2026-07-02 Update README with printing settings and rack notes
    Added details about printing settings and rack design considerations.
2026-07-02 additional schematics for hardware readme
2026-07-02 Revise printing instructions and building sections
    Updated the printing instructions and added details for building the lids and multiflipper.
2026-07-02 Add images for gluing instructions in README
    Added images to illustrate the gluing process for the tube array, mesh, multiflipper base, and magnets.
2026-07-02 Fix thumbnail link for tube cutting video
    Updated the thumbnail image link for the tube cutting video.
2026-10-08 remove STL embedding into readme
2026-10-08 embed STL as AST into readme
2026-10-09 Revise tube cutting instructions and remove redundancy
    Updated instructions for obtaining and cutting tubes for the chambers. Removed redundant section on cutting tubes and added details on using a tube cutter.
2026-10-09 Revise README for Drosben assembly instructions
    Updated assembly instructions for Drosben components, including details on gluing techniques, materials, and modifications for improved clarity and safety.
2026-10-09 Update README with assembly safety warnings
    Added cautionary notes regarding assembly risks.
2026-10-09 Fix duplicate tip on magnet orientation
    Removed duplicate important tip about magnet orientation.
2026-10-09 sample files for the manual
